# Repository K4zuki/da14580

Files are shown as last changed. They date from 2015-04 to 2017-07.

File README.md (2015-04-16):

# da14580
DA14580/murata module PCBs

<br />This work is licensed under a <a rel="license" href="http://creativecommons.org/licenses/by-sa/4.0/">Creative Commons Attribution-ShareAlike 4.0 International License</a>.

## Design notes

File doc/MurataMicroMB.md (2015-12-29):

# `r0.2` BOM list
| Qty | Value |  AKIZUKI/DIGIKEY/MOUSER  | Parts |
|:---:|:---|:---:|:---|
| | | **DIGIKEY** | |
| 1*  | CORESIGHT10 | 1175-1627-ND | CON3 |
|  1  | 12M/3225 | 1253-1168-1-ND | Q1 |
|  1  | LM27313 | 296-35164-1-ND | IC2 |
| 4*  | TESTPAD\_4020 | 36-5019CT-ND | TP13, TP14, TP15, TP16 |
|  1  | 4.7u/2016 | 445-7844-1-ND | L1 |
|  4  | 0.1u/1005 | 490-3261-1-ND | C1, C7, C10, C11 |
|  4  | 18p/1005 | 490-5858-1-ND | C3, C12, C13, C14 |
|  4  | 4.7u/2012 | 490-9962-1-ND | C4, C5, C8, C9 |
|  1  | IC\_LPC11U35\_QFN33\_5X5 | 568-9586-ND | IC3 |
|  1  | RD/GR | 754-1633-1-ND | LED1 |
| 4*  | TESTPAD\_1608 | A106145CT-ND | TP1, TP2, TP3, TP4 |
|  1  | LDO4\_3.3\_SOT223 | AZ1117EH-3.3TRG1DICT-ND  | IC4 |
| 2*  | CON\_MICROSD\_C2395 | HR1964CT-ND | CON1, CON4 |
|  1  | SINGLE\_74\_00 | NC7SZ00M5XCT-ND | IC5 |
| 4*  | 1k/1005 | P1.00KLCT-ND | R5, R6, R15, R16 |
|  1  | 1.5k/1005 | P1.50KLCT-ND | R11 |
|  9  | 10k/1005 | P10.0KLCT-ND | R2, R7, R8, R9, R12, R17, R18, R19, R20 |
|  2  | 100/1005 | P100LCT-ND | R13, R14 |
|  1  | P13.3KHCT-ND | P13.3KHCT-ND | R4 |
| 2*  | 33/1005 | P33.0LCT-ND | R1, R10 |
|  1  | P60.4KHCT-ND | P60.4KHCT-ND | R3 |
| 1*  | 40V2A | SS24FLCT-ND | D1 |
|  1  | WM17143CT-ND | WM17143CT-ND | CON2 |
| | | **AKIZUKI** | |
|  1  | TSW-102-02-S-S | 1/10 C-08593 | X1 |
|  1  | BSS84 |  I-04269/I-04270(reel) | TR1 |
|  2  | 0.1u/1608 | P-05650 | C2, C15 |
| 2*  | P-8073 | P-08073 | SW1, SW3 |
| 1*  | P-8073 | P-08214 | SW2 |
| | | **NOT\_COMPONENT** | |
|  1  | | ICON\_OSHW | U$1 |
|  8  | | TESTPAD | TP5, TP6, TP7, TP8, TP9, TP10, TP11, TP12 |
|  3  | | TESTPAD\_F | TP101, TP102, TP103 |
|  1  | PCB\_DP\_RECTANGLE-43X70 | PCB\_DP\_RECTANGLE-43X70 | PCB1 |
|  1  | NM/1608 | C\_SMD\_\_1608 | C6 |

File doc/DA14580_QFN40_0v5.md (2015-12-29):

# `v0.5` BOM list
| Qty | Parts | | | |
|:---:|:---|:---|:---|:---|
| | **AKIZUKI** | | | |
|  1  | IC3 | I-05448 | LDO5\_3.3\_SOT23 | LDO5\_3.3\_SOT23 |
| | **DIGIKEY** | | | |
|  1  | L1 | 445-6385-1-ND | 2.2u/1608 | INDUCTOR\_2.2U\_1608 |
|  3  | C4, C5, C10 | 490-3261-1-ND | 0.1u/1005 | C\_SMD\_0.1U\_1005 |
|  4  | C1, C2, C3, C9 | 490-3890-1-ND | 1.0u/1005 | C\_SMD\_1.0U\_1005 |
|  1  | Q1 | 1253-1342-1-ND | 32.768k | CRYSTAL2\_32.768K\_FC-135 |
|  1  | Q2 | 887-1833-1-ND | 16M/2520 | CRYSTAL4\_16M\_2520 |
|  1  | IC2 | NC7SZ00M5XCT-ND | NC7SZ00M5XCT-ND | 74LVC1G00DBV |
|  1  | R1 | P10.0KLCT-ND | 10k/1005 | R\_US\_10K\_1005 |
| | **MOUSER** | | | |
|  1  | U1 | 724-DA14583-01AT2  | DA14583-AT2 | DA14583AT2 |
| | **PLACED BUT UNUSED** | | | |
|  0  | IC1 | 1265-1137-1-ND | AT25XE011\_SOP | IC\_MEMORY\_8P\_AT25XE011\_SOP |
|  0  | X1, X2 | SSW-114-02-S-S | SSW-114-02-S-S | SSW-114-02-S-S |
|  0  | C6 | 490-5921-1-ND | NM | C\_SMD\_10P\_1005 |
|  0  | C7, C8 | NM | C\_SMD\_\_1005 | C0402 |
| | **NOT COMPONENTS** | | | |
|  0  | U$1 | ANT\_IFA | ANT\_IFA | ANT\_IFA\_V2 |
|  0  | CON1 | CON\_TC2030-CTL-NL | CON\_TC2030-CTL-NL | CON\_TC2030-IDC-NL |
|  0  | U$2 | ICON\_OSHW | ICON\_OSHW | ICON\_OSHW |
|  0  | TP1, TP2 | TESTPAD | TESTPAD | TP06RECT |
|  0  | TP91, TP92, TP93 | TESTPAD\_F | TESTPAD\_F | FIDUCIAL |
|  0  | TP3 | TPPAD1-13 | TPPAD1-13 | P1-13 |

Table: http://www.digikey.com/short/t0j4bd

| ID | ref | desc. | count | comment |
|:---|:---|:---|:---|:---|
| 445-6385-1-ND | L1 | FIXED IND 2.2UH 500MA 250 MOHM  | 25 | Cut tape  |
| 1253-1342-1-ND  | Q1 | CRYSTAL 32.7680KHZ 7PF SMD | 25 | Cut tape  |
| 887-1833-1-ND | Q2 | CRYSTAL 16.0000MHZ 12PF SMD | 25 | Cut tape  |
| NC7SZ00M5XCT-ND | IC2 | IC GATE NAND 1CH 2-INP SOT-23-5 | 25 | Cut tape  |
| P10.0KLDKR-ND | R1 | RES SMD 10K OHM 1% 1/10W 0402 | 1000  | Digi-Reel |
| 490-3261-6-ND | C4/ 5/ 10 | CAP CER 0.1UF 16V X7R 0402 | 1000  | Digi-Reel |
| 490-3890-6-ND | C1-3/ 9 | CAP CER 1UF 10V X5R 0402 | 1000  | Digi-Reel |

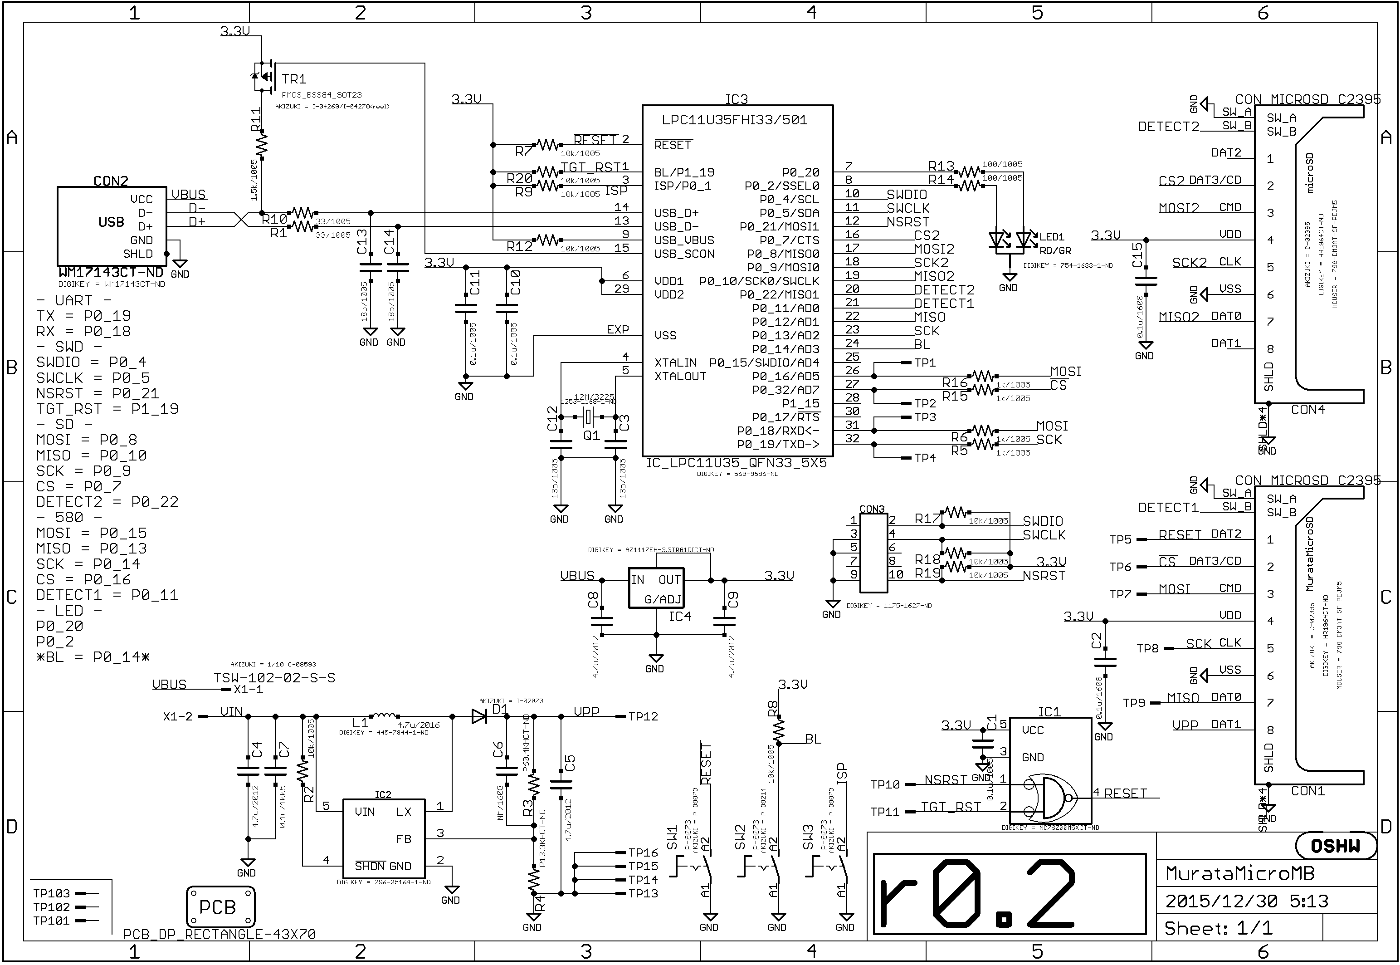
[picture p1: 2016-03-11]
images/MurataMicroMBr02.sch.png

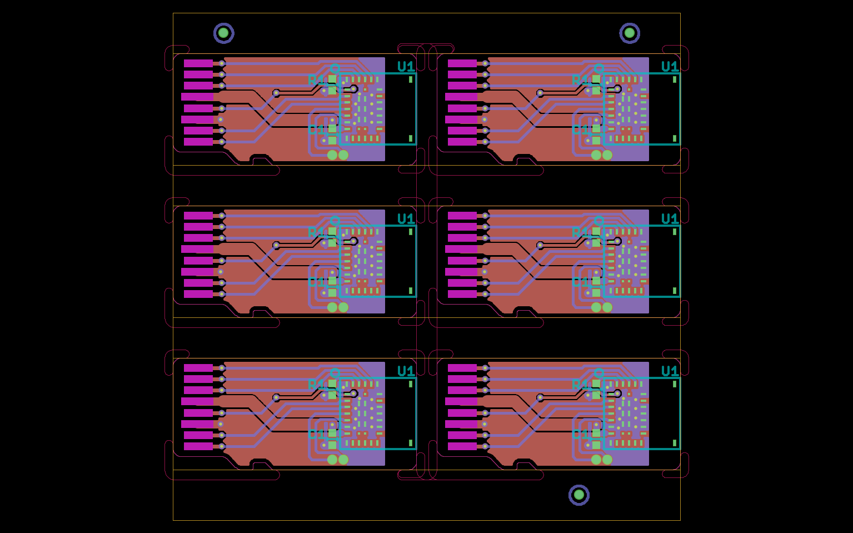
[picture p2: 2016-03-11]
images/MurataMicroSD_P.png

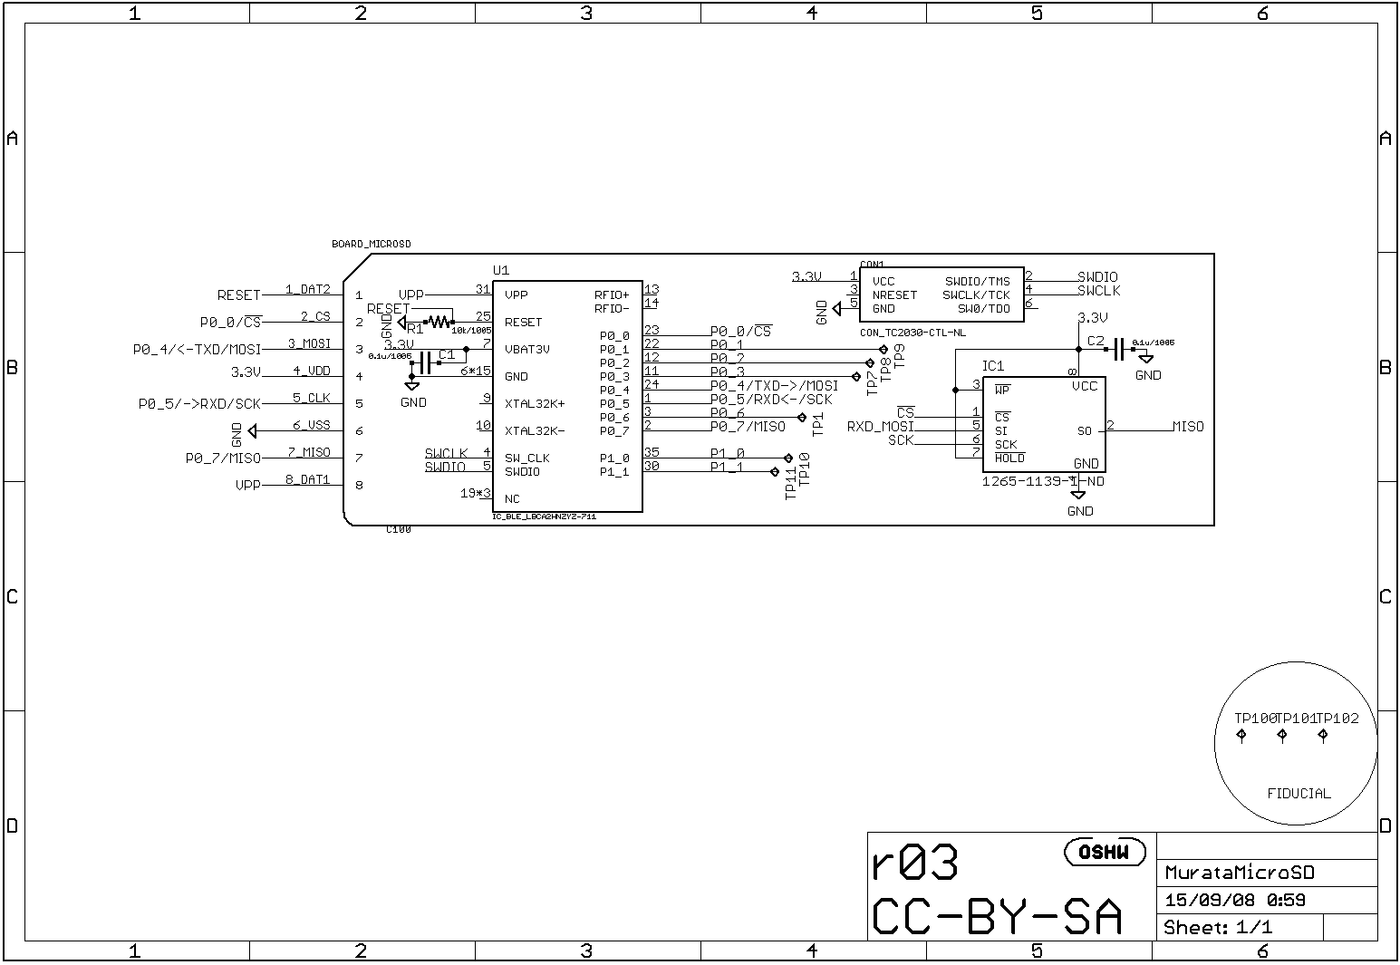
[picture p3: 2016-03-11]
images/MurataMicroSD.sch.png

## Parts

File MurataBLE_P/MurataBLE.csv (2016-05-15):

Part | Value | Device | Package | Description | AKIZUKI | DIGIKEY | MOUSER | NOT_COMPONENT | SEEED
C1 | 1u/1608 | C_SMD_1.0U_1608 | CR_1608 | SMD CAPACITOR |  |  |  |  | 302010139
C2 | 0.1u/1005 | C_SMD_0.1U_1005 | C0402 | SMD CAPACITOR |  | 490-3261-1-ND |  |  | 302010024
C3 | 1u/1608 | C_SMD_1.0U_1608 | CR_1608 | SMD CAPACITOR |  |  |  |  | 302010139
C4 | 0.1u/1005 | C_SMD_0.1U_1005 | C0402 | SMD CAPACITOR |  | 490-3261-1-ND |  |  | 302010024
C5 | 0.1u/1005 | C_SMD_0.1U_1005 | C0402 | SMD CAPACITOR |  | 490-3261-1-ND |  |  | 302010024
C6 | 0.1u/1005 | C_SMD_0.1U_1005 | C0402 | SMD CAPACITOR |  | 490-3261-1-ND |  |  | 302010024
C7 | 18p/1005 | C_SMD_18P_1005 | C0402 | SMD CAPACITOR |  | 490-5858-1-ND |  |  | 302010016
C8 | 18p/1005 | C_SMD_18P_1005 | C0402 | SMD CAPACITOR |  | 490-5858-1-ND |  |  | 302010016
C9 | 18p/1005 | C_SMD_18P_1005 | C0402 | SMD CAPACITOR |  | 490-5858-1-ND |  |  | 302010016
C10 | 18p/1005 | C_SMD_18P_1005 | C0402 | SMD CAPACITOR |  | 490-5858-1-ND |  |  | 302010016
C13 | 0.1u/1005 | C_SMD_0.1U_1005 | C0402 | SMD CAPACITOR |  | 490-3261-1-ND |  |  | 302010024
CON1 | 47589-0001 | CON_USB_UB | CON_USB_47589-0001MOLEX | USB B CONNECTOR |  | WM17143CT-ND
IC1 | TLV1117-33IDRJR | LDO4_3.3_DRJ | DFN80P410X410_8N | LDO with 4 pins |  | 296-32364-1-ND
IC2 | LPC11U35_QFN33 | IC_LPC11U35_QFN33_5X5 | HVQFN33 |  |  | 568-9586-ND |  |  | 310010053
IC3 | NC7SZ00 | IC_TTL_SINGLE_74_00_SOT23 | SOT95P280X145-5N | SINGLE 2-INPUT POSITIVE-OR GATE |  | NC7SZ00M5XCT-ND
LED1 | LED_3SEG | LED_3SEG | LED_3SEG_SMD | Vf@5mA: |  |  | 604-APF3236SEEZGQBDC
LED2 | LED_3SEG | LED_3SEG | LED_3SEG_SMD | Vf@5mA: |  |  | 604-APF3236SEEZGQBDC
Q1 | 32.768K/2012 | CRYSTAL2_32.768K_2012 | CR_2125 |  |  | 1253-1342-1-ND
Q2 | 12M/3225 | CRYSTAL4_12M_3225 | CLOCK_3225 | Crystal 4 pins |  | 1253-1168-1-ND
R1 | 10k/1005 | R_US_10K_1005 | C0402 | SMD resistor |  | P10.0KLCT-ND |  |  | 301010047
R2 | 33/1005 | R_US_33R_1005 | C0402 | SMD resistor |  | P33.0LCT-ND |  |  | 301010609
R3 | 33/1005 | R_US_33R_1005 | C0402 | SMD resistor |  | P33.0LCT-ND |  |  | 301010609
R4 | 1k/1005 | R_US_1.0K_1005 | C0402 | SMD resistor |  | P1.00KLCT-ND |  |  | 301010006
R5 | 1k/1005 | R_US_1.0K_1005 | C0402 | SMD resistor |  | P1.00KLCT-ND |  |  | 301010006
R6 | 10k/1005 | R_US_10K_1005 | C0402 | SMD resistor |  | P10.0KLCT-ND |  |  | 301010047
R7 | 10k/1005 | R_US_10K_1005 | C0402 | SMD resistor |  | P10.0KLCT-ND |  |  | 301010047
R8 | 10k/1005 | R_US_10K_1005 | C0402 | SMD resistor |  | P10.0KLCT-ND |  |  | 301010047
R9 | 10k/1005 | R_US_10K_1005 | C0402 | SMD resistor |  | P10.0KLCT-ND |  |  | 301010047
R10 | 1.5k/1005 | R_US_1.5K_1005 | C0402 | SMD resistor |  | P1.50KLCT-ND |  |  | 301010001
R11 | 1k/1005 | R_US_1.0K_1005 | C0402 | SMD resistor |  | P1.00KLCT-ND |  |  | 301010006
R14 | 10k/1005 | R_US_10K_1005 | C0402 | SMD resistor |  | P10.0KLCT-ND |  |  | 301010047
R15 | 10k/1005 | R_US_10K_1005 | C0402 | SMD resistor |  | P10.0KLCT-ND |  |  | 301010047
R16 | 1k/1005 | R_US_1.0K_1005 | C0402 | SMD resistor |  | P1.00KLCT-ND |  |  | 301010006
R17 | 1k/1005 | R_US_1.0K_1005 | C0402 | SMD resistor |  | P1.00KLCT-ND |  |  | 301010006
R18 | 1k/1005 | R_US_1.0K_1005 | C0402 | SMD resistor |  | P1.00KLCT-ND |  |  | 301010006
SW1 | FSM2JMTR | TACTSW2_FSM2JMTR | SW_TACTSW_FSM2JMTR | 2P tact switch |  | 450-2146-1-ND
SW2 | FSM2JMTR | TACTSW2_FSM2JMTR | SW_TACTSW_FSM2JMTR | 2P tact switch |  | 450-2146-1-ND
SW3 | FSM2JMTR | TACTSW2_FSM2JMTR | SW_TACTSW_FSM2JMTR | 2P tact switch |  | 450-2146-1-ND
TR1 | BSS84 | PMOS_BSS84_SOT23 | SOT95P300X140-3N |  | I-04269/I-04270(reel) | BSS84CT-ND
U1 | LBCA2HNZYZ | LBCA2HNZYZ-711 | IC_MURATA_LBCA2HNZYZ-711 |  |  | 490-10561-1-ND | 81-LBCA2HNZYZ-711

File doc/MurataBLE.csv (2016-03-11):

Qty | Value | Device | Package | Parts | Description | AKIZUKI | DIGIKEY | MOUSER | NOT_COMPONENT | SEEED
1 |  | CON_USB_UB | CON_USB_47589-0001MOLEX | CON1 | USB B CONNECTOR |  | WM17143CT-ND
1 |  | CRYSTAL2_32.768K_2012 | CR_2125 | Q1 |  |  | 1253-1342-1-ND
1 |  | CRYSTAL4_12M_3225 | CLOCK_3225 | Q2 | Crystal 4 pins |  | 1253-1168-1-ND
1 |  | GIT-REVISION | GIT-REVISION | GIT1 |  |  |  |  | YES
1 |  | ICON_OSHW | ICON_OSHW | ICON2 | Silk icon of OSHW |  |  |  | YES
1 |  | IC_LPC11U35_QFN33_5X5 | HVQFN33 | IC2 |  |  | 568-9586-ND |  |  | 310010053
1 |  | IC_MEMORY_8P_AT25DN512C_SOP | IC_08_1.27_150MIL | IC4 |  |  |  | 988-A25DN512CSSHFGPT (cuttape)
1 |  | IC_MEMORY_8P_AT25XE011_SOP | IC_08_1.27_150MIL | IC5 |  |  | 1265-1137-1-ND
1 |  | IC_TTL_SINGLE_74_00_SOT23 | SOT95P280X145-5N | IC3 | SINGLE 2-INPUT POSITIVE-OR GATE |  | NC7SZ00M5XCT-ND
1 |  | LBCA2HNZYZ-711 | IC_MURATA_LBCA2HNZYZ-711 | U1 |  |  | 490-10561-1-ND | 81-LBCA2HNZYZ-711
4 |  | PCB_CORNER_NH | PCB_CORNER_NH | P1, P2, P3, P4 |  |  |  |  | YES
3 |  | R_US_1.0K_1005 | C0402 | R4, R5, R11 | SMD resistor |  | P1.00KLCT-ND |  |  | 301010006
2 |  | R_US__1005SHORT | R0402SHORT | R12, R13 | SMD resistor |  |  |  | YES
3 |  | TACTSW2_FSM2JMTR | SW_TACTSW_FSM2JMTR | SW1, SW2, SW3 | 2P tact switch |  | 450-2146-1-ND
7 | 0.1u/1005 | C_SMD_0.1U_1005 | C0402 | C2, C4, C5, C6, C11, C12, C13 | SMD CAPACITOR |  | 490-3261-1-ND |  |  | 302010024
1 | 1.5k/1005 | R_US_1.5K_1005 | C0402 | R10 | SMD resistor |  | P1.50KLCT-ND |  |  | 301010001
5 | 10k/1005 | R_US_10K_1005 | C0402 | R1, R6, R7, R8, R9 | SMD resistor |  | P10.0KLCT-ND |  |  | 301010047
4 | 18p/1005 | C_SMD_18P_1005 | C0402 | C7, C8, C9, C10 | SMD CAPACITOR |  | 490-5858-1-ND |  |  | 302010016
2 | 1u/1608 | C_SMD_1.0U_1608 | CR_1608 | C1, C3 | SMD CAPACITOR |  |  |  |  | 302010139
2 | 33/1005 | R_US_33R_1005 | C0402 | R2, R3 | SMD resistor |  | P33.0LCT-ND |  |  | 301010609
1 | I-5448 | LDO5_3.3_SOT23 | SOT95P280X145-5N | IC1 |  | I-05448
1 | LED_3SEG | LED_3SEG | LED_3SEG_SMD | LED1 | Vf@5mA: |  |  | 604-APF3236SEEZGQBDC
1 | PMOS_BSS84_SOT23 | PMOS_BSS84_SOT23 | SOT95P300X140-3N | TR1 |  | I-04269/I-04270(reel) | BSS84CT-ND
3 | TESTPAD_F | TESTPAD_F | FIDUCIAL | TP100, TP101, TP102 | test points |  |  |  | YES
2 | TSW-114-02-S-S | TSW-114-02-S-S | TSW-114-07-F-S | X1, X2 | THROUGH-HOLE .025inch SQ POST HEADER | C-04397 |  |  | YES
1 | r0.4 | ICON_REVISION_1.2 | ICON_REVISION1.2 | ICON1 |  |  |  |  | YES

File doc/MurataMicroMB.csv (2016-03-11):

Qty | Value | Parts | DIGIKEY | SEEED
1 | CON_MIL_10_ARM | CON3 | 1175-1627-ND
1 | LM27313 | IC2 | 296-35164-1-ND
1 | NC7SZ00 | IC1 | NC7SZ00M5XCT-ND
1 | LDO4_3.3_DRJ | IC4 | 296-32364-1-ND
3 | TACTSW2_FSM2JMTR | SW1, SW2, SW3 | 450-2146-1-ND
4 | TESTPAD_4020 | TP13, TP14, TP15, TP16 | 36-5019CT-ND
4 | 0.1u/1005 | C1, C7, C10, C11 | 490-3261-1-ND | 302010024
1 | 1.5k/1005 | R11 | P1.50KLCT-ND | 301010001
9 | 10k/1005 | R2, R7, R8, R9, R12, R17, R18, R19, R20 | P10.0KLCT-ND | 301010047
1 | 12M/3225 | Q1 | 1253-1168-1-ND
4 | 18p/1005 | C3, C12, C13, C14 | 490-5858-1-ND | 302010016
4 | 1k/1005 | R5, R6, R15, R16 | P1.00KLCT-ND | 301010006
2 | 33/1005 | R1, R10 | P33.0LCT-ND | 301010609
4 | 4.7u/2012 | C4, C5, C8, C9 | 490-9962-1-ND
1 | 4.7u/2016 | L1 | 445-7844-1-ND
1 | 40V2A | D1 | SS24FLCT-ND
2 | CON_MICROSD_C2395 | CON1, CON4 | HR1964CT-ND
1 | LPC11U35_5X5 | IC3 | 568-9586-ND | 310010053
1 | 13.3K/1608 | R4 | P13.3KHCT-ND
1 | BSS84 | TR1 | BSS84CT-ND
4 | TESTPAD_1608 | TP1, TP2, TP3, TP4 | A106145CT-ND
1 | TSW-102-02-S-S | X1 | S1011EC-02-ND | 320020016
1 | WM17143CT-ND | CON2 | WM17143CT-ND

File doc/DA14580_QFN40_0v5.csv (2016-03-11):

Qty | Parts | AKIZUKI | DIGIKEY | MOUSER
1 | IC3 | I-05448 | LDO5_3.3_SOT23 | LDO5_3.3_SOT23
1 | IC1 | 1265-1137-1-ND | AT25XE011_SOP | IC_MEMORY_8P_AT25XE011_SOP
1 | L1 | 445-6385-1-ND | 2.2u/1608 | INDUCTOR_2.2U_1608
3 | C4, C5, C10 | 490-3261-1-ND | 0.1u/1005 | C_SMD_0.1U_1005
4 | C1, C2, C3, C9 | 490-3890-1-ND | 1.0u/1005 | C_SMD_1.0U_1005
1 | Q1 | 728-1076-1-ND | 32.768k | CRYSTAL2_32.768K_FC-135
1 | Q2 | 887-1833-1-ND | 16M/2520 | CRYSTAL4_16M_2520
1 | IC2 | NC7SZ00M5XCT-ND | NC7SZ00M5XCT-ND | 74LVC1G00DBV
1 | R1 | P10.0KLCT-ND | 10k/1005 | R_US_10K_1005
1 | U1 | 724-DA14583-01AT2 | DA14583-AT2 | DA14583AT2
0 | X1, X2 | SSW-114-02-S-S | SSW-114-02-S-S | SSW-114-02-S-S
0 | U$1 | ANT_IFA | ANT_IFA | ANT_IFA_V2
0 | CON1 | CON_TC2030-CTL-NL | CON_TC2030-CTL-NL | CON_TC2030-IDC-NL
0 | U$2 | ICON_OSHW | ICON_OSHW | ICON_OSHW
0 | C6 | 490-5921-1-ND | NM | C_SMD_10P_1005
0 | C7, C8 | NM | C_SMD__1005 | C0402
0 | TP1, TP2 | TESTPAD | TESTPAD | TP06RECT
0 | TP91, TP92, TP93 | TESTPAD_F | TESTPAD_F | FIDUCIAL
0 | TP3 | TPPAD1-13 | TPPAD1-13 | P1-13

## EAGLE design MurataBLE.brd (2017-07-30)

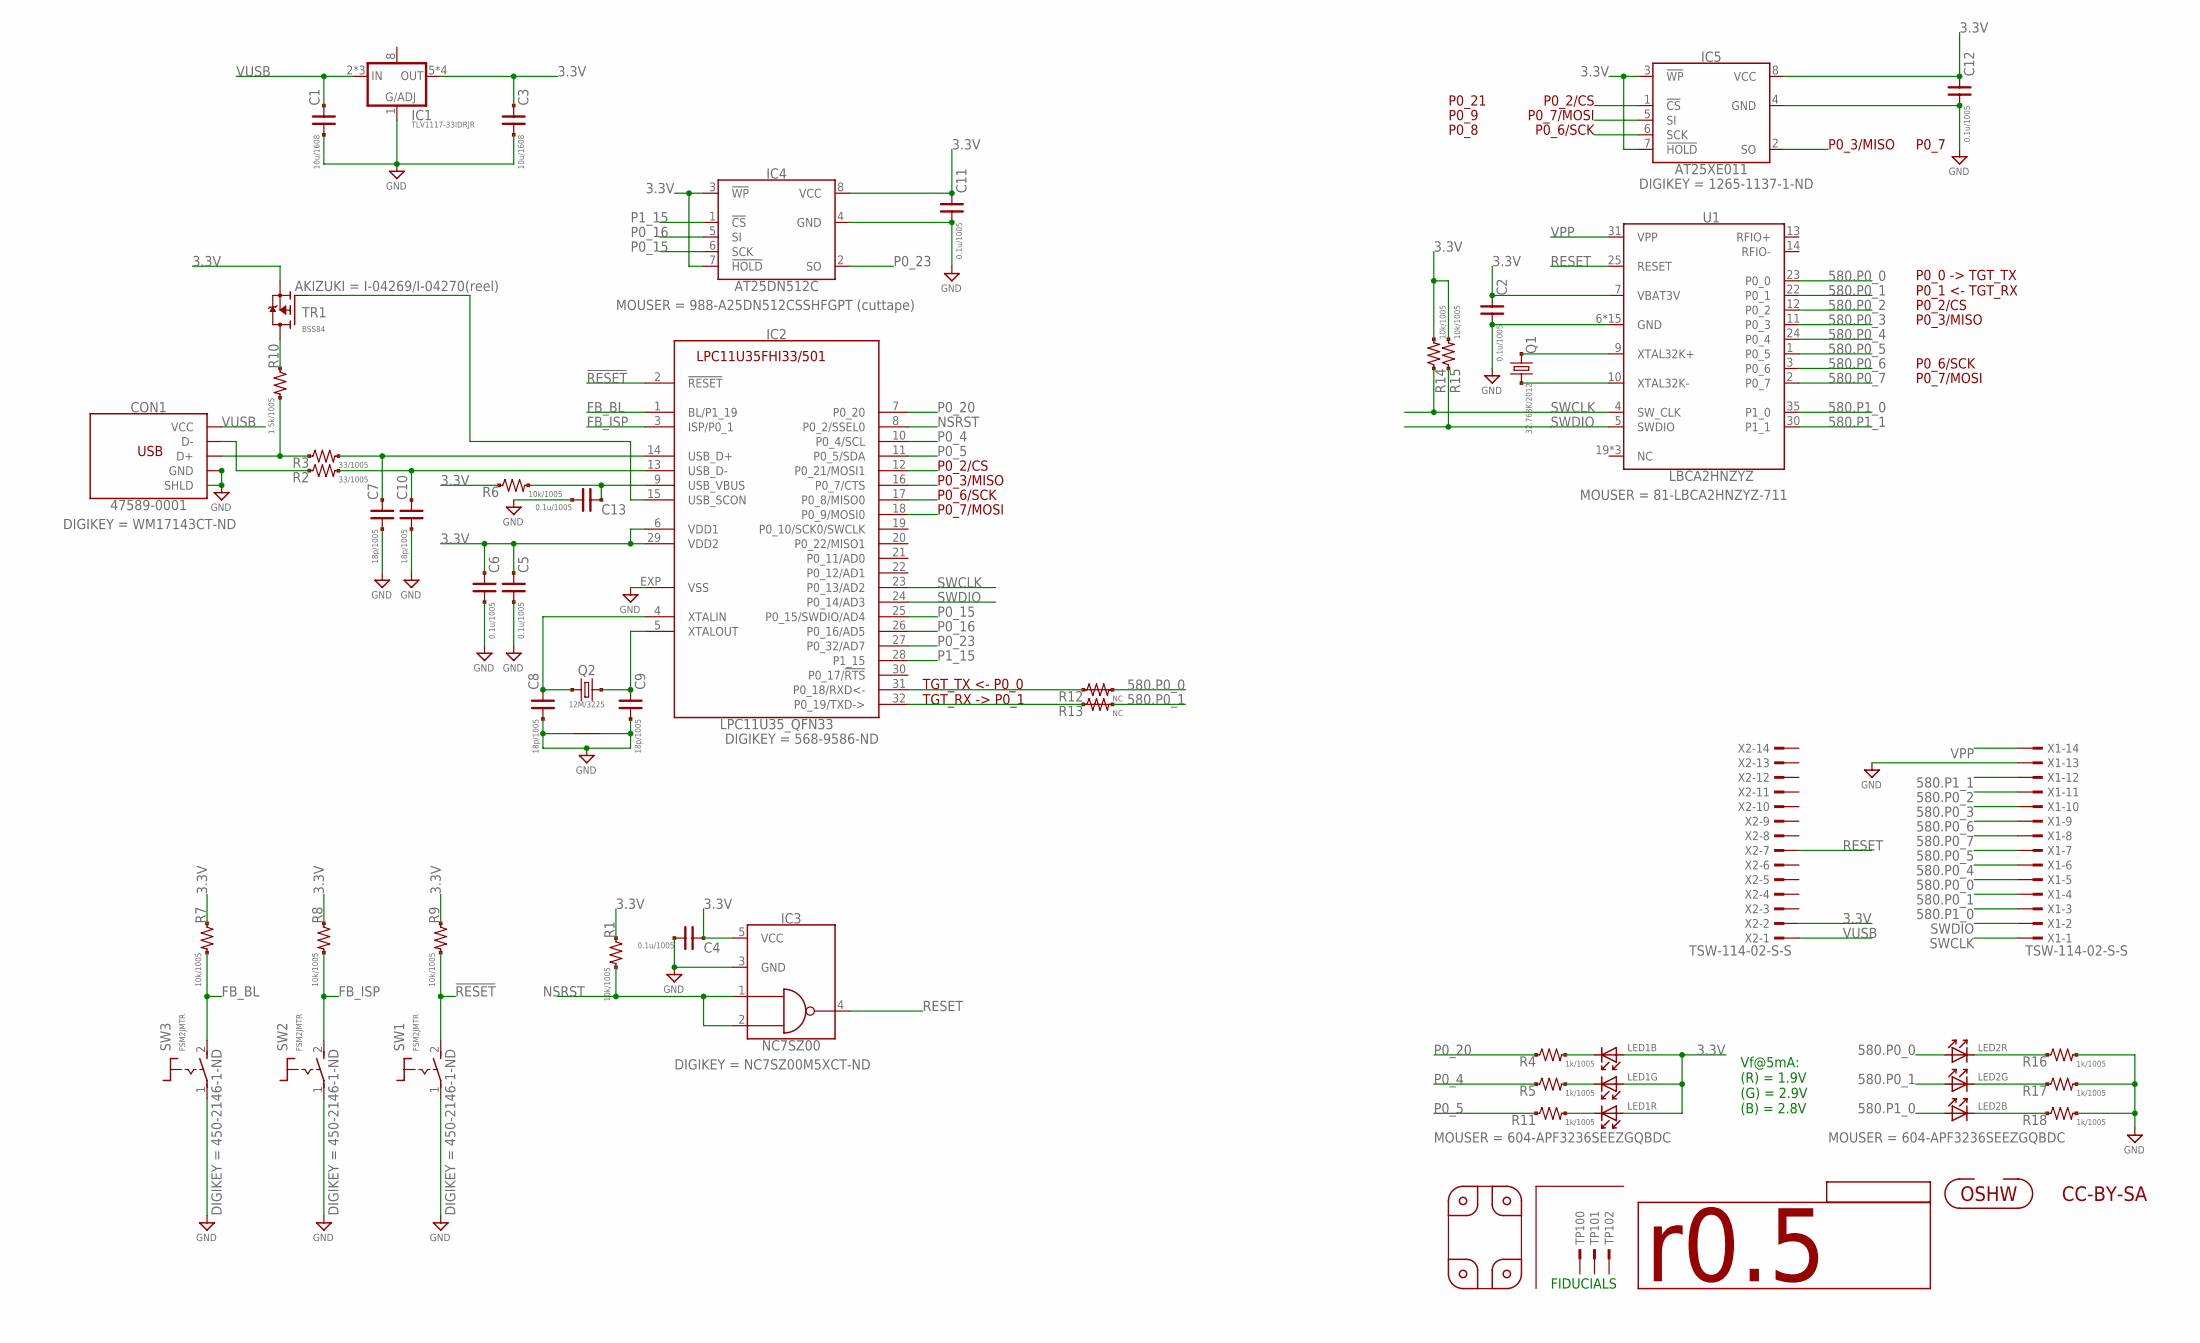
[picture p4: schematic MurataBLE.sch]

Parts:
C1, C3: 10u/1608; CR_1608
C2, C4, C5, C6, C11, C12, C13: 0.1u/1005; C0402
C7, C8, C9, C10: 18p/1005; C0402
CON1: 47589-0001; CON_USB_47589-0001MOLEX
GIT1: GIT-REVISION
IC1: TLV1117-33IDRJR; DFN80P410X410_8N
IC2: LPC11U35_QFN33; HVQFN33
IC3: NC7SZ00; SOT95P280X145-5N
IC4: AT25DN512C; IC_08_1.27_150MIL
IC5: AT25XE011; IC_08_1.27_150MIL
ICON1: r0.5; ICON_REVISION1.2
ICON2: NC; ICON_OSHW
LED1, LED2: LED_3SEG; LED_3SEG_SMD
P1, P2, P3, P4: NC; PCB_CORNER_NH
Q1: 32.768K/2012; CR_2125
Q2: 12M/3225; CLOCK_3225
R1, R6, R7, R8, R9, R14, R15: 10k/1005; C0402
R2, R3: 33/1005; C0402
R4, R5, R11, R16, R17, R18: 1k/1005; C0402
R10: 1.5k/1005; C0402
R12, R13: NC; R0402SHORT
SW1, SW2, SW3: FSM2JMTR; SW_TACTSW_FSM2JMTR
TP100, TP101, TP102: NC; FIDUCIAL
TR1: BSS84; SOT95P300X140-3N
U1: LBCA2HNZYZ; IC_MURATA_LBCA2HNZYZ-711
X1, X2: TSW-114-02-S-S; TSW-114-07-F-S

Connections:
3.3V: C2.1, C3.1, C4.1, C5.1, C6.1, C11.1, C12.1, IC1.5 (OUT), IC1.6 (OUT), IC1.7 (OUT), IC1.EP (OUT), IC2.6 (VDD1), IC2.29 (VDD2), IC3.5 (VCC), IC4.3 (!WP), IC4.7 (!HOLD), IC4.8 (VCC), IC5.3 (!WP), IC5.7 (!HOLD), IC5.8 (VCC), LED1.4 (A), LED1.5 (A), LED1.6 (A), R1.1, R6.1, R7.1, R8.1, R9.1, R14.2, R15.2, TR1.2 (S), U1.7 (VBAT3V), X2.2
580.P0_0: LED2.4 (A), R12.3 (2), U1.23 (P0_0), X1.5
580.P0_1: LED2.5 (A), R13.3 (2), U1.22 (P0_1), X1.4
580.P0_2: IC2.12 (P0_21/MOSI1), IC5.1 (!CS), U1.12 (P0_2), X1.11
580.P0_3: IC2.16 (P0_7/CTS), IC5.2 (SO), U1.11 (P0_3), X1.10
580.P0_4: U1.24 (P0_4), X1.6
580.P0_5: U1.1 (P0_5), X1.7
580.P0_6: IC2.17 (P0_8/MISO0), IC5.6 (SCK), U1.3 (P0_6), X1.9
580.P0_7: IC2.18 (P0_9/MOSI0), IC5.5 (SI), U1.2 (P0_7), X1.8
580.P1_0: LED2.6 (A), U1.35 (P1_0), X1.3
580.P1_1: U1.30 (P1_1), X1.12
!RESET!: IC2.2 (!RESET!), R9.2, SW1.2 (S)
FB_BL: IC2.1 (BL/P1_19), R7.2, SW3.2 (S)
FB_ISP: IC2.3 (ISP/P0_1), R8.2, SW2.2 (S)
GND: C1.2, C2.2, C3.2, C4.2, C5.2, C6.2, C7.2, C8.2, C9.2, C10.2, C11.2, C12.2, C13.2, CON1.5 (GND), CON1.SHD (SHLD), CON1.SHD$1 (SHLD), CON1.SHD$2 (SHLD), CON1.SHD$3 (SHLD), CON1.SHD$4 (SHLD), CON1.SHD$5 (SHLD), CON1.SHD$6 (SHLD), CON1.SHD$7 (SHLD), IC1.1 (ADJ), IC2.EXP (VSS), IC3.3 (GND), IC4.4 (GND), IC5.4 (GND), Q2.2, Q2.4, R16.2, R17.2, R18.2, SW1.1, SW2.1, SW3.1, U1.6 (GND), U1.8 (GND), U1.15 (GND), U1.16 (GND), U1.17 (GND), U1.18 (GND), U1.20 (GND), U1.21 (GND), U1.26 (GND), U1.27 (GND), U1.28 (GND), U1.29 (GND), U1.32 (GND), U1.33 (GND), U1.34 (GND), X1.13
unnamed: Q1.1, U1.9 (XTAL32K+)
unnamed: Q1.2, U1.10 (XTAL32K-)
unnamed: C13.1, IC2.9 (USB_VBUS), R6.2
unnamed: R10.1, TR1.3 (D)
unnamed: IC2.15 (USB_SCON), TR1.1 (G)
unnamed: LED1.1 (K), R11.2
unnamed: LED1.2 (K), R5.2
unnamed: LED1.3 (K), R4.2
unnamed: LED2.3 (K), R18.1
unnamed: LED2.2 (K), R17.1
unnamed: LED2.1 (K), R16.1
unnamed: C8.1, IC2.4 (XTALIN), Q2.1
unnamed: C9.1, IC2.5 (XTALOUT), Q2.3 (2)
unnamed: C7.1, IC2.14 (USB_D+), R3.2
unnamed: CON1.3 (D+), R3.1, R10.2
unnamed: CON1.2 (D-), R2.1
unnamed: C10.1, IC2.13 (USB_D-), R2.2
NSRST: IC2.8 (P0_2/SSEL0), IC3.1 (1A), IC3.2 (1B), R1.2
P0_4: IC2.10 (P0_4/SCL), R5.1
P0_5: IC2.11 (P0_5/SDA), R11.1
P0_15: IC2.25 (P0_15/SWDIO/AD4), IC4.6 (SCK)
P0_16: IC2.26 (P0_16/AD5), IC4.5 (SI)
P0_20: IC2.7 (P0_20), R4.1
P0_23: IC2.27 (P0_32/AD7), IC4.2 (SO)
P1_15: IC2.28 (P1_15), IC4.1 (!CS)
RESET: IC3.4 (1Y), U1.25 (RESET), X2.7
SWCLK: IC2.23 (P0_13/AD2), R14.1, U1.4 (SW_CLK), X1.1
SWDIO: IC2.24 (P0_14/AD3), R15.1, U1.5 (SWDIO), X1.2
TGT_RX: IC2.32 (P0_19/TXD->), R13.1, R13.2 (1)
TGT_TX: IC2.31 (P0_18/RXD<-), R12.1, R12.2 (1)
VPP: U1.31 (VPP), X1.14
VUSB: C1.1, CON1.1 (VCC), IC1.2 (IN), IC1.3 (IN), IC1.4 (IN), X2.1

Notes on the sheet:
Vf@5mA: (R) = 1.9V (G) = 2.9V (B) = 2.8V
TGT_TX <- P0_0 TGT_RX -> P0_1
P0_0 -> TGT_TX P0_1 <- TGT_RX
CC-BY-SA
FIDUCIALS
P0_2/CS
P0_7/MOSI
P0_3/MISO
P0_6/SCK
P0_21
P0_9
P0_8
P0_7

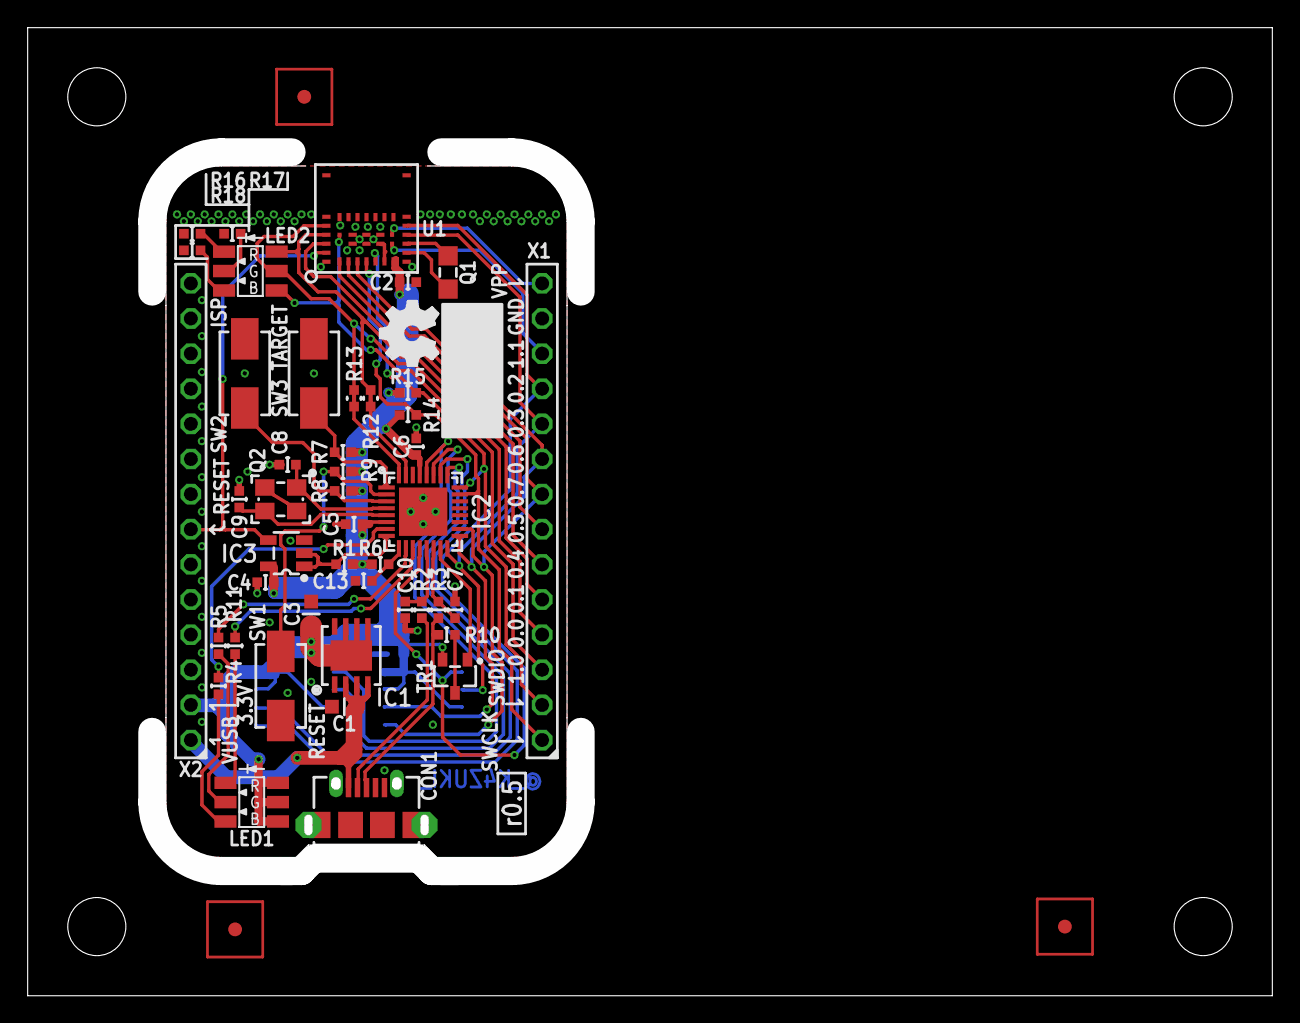
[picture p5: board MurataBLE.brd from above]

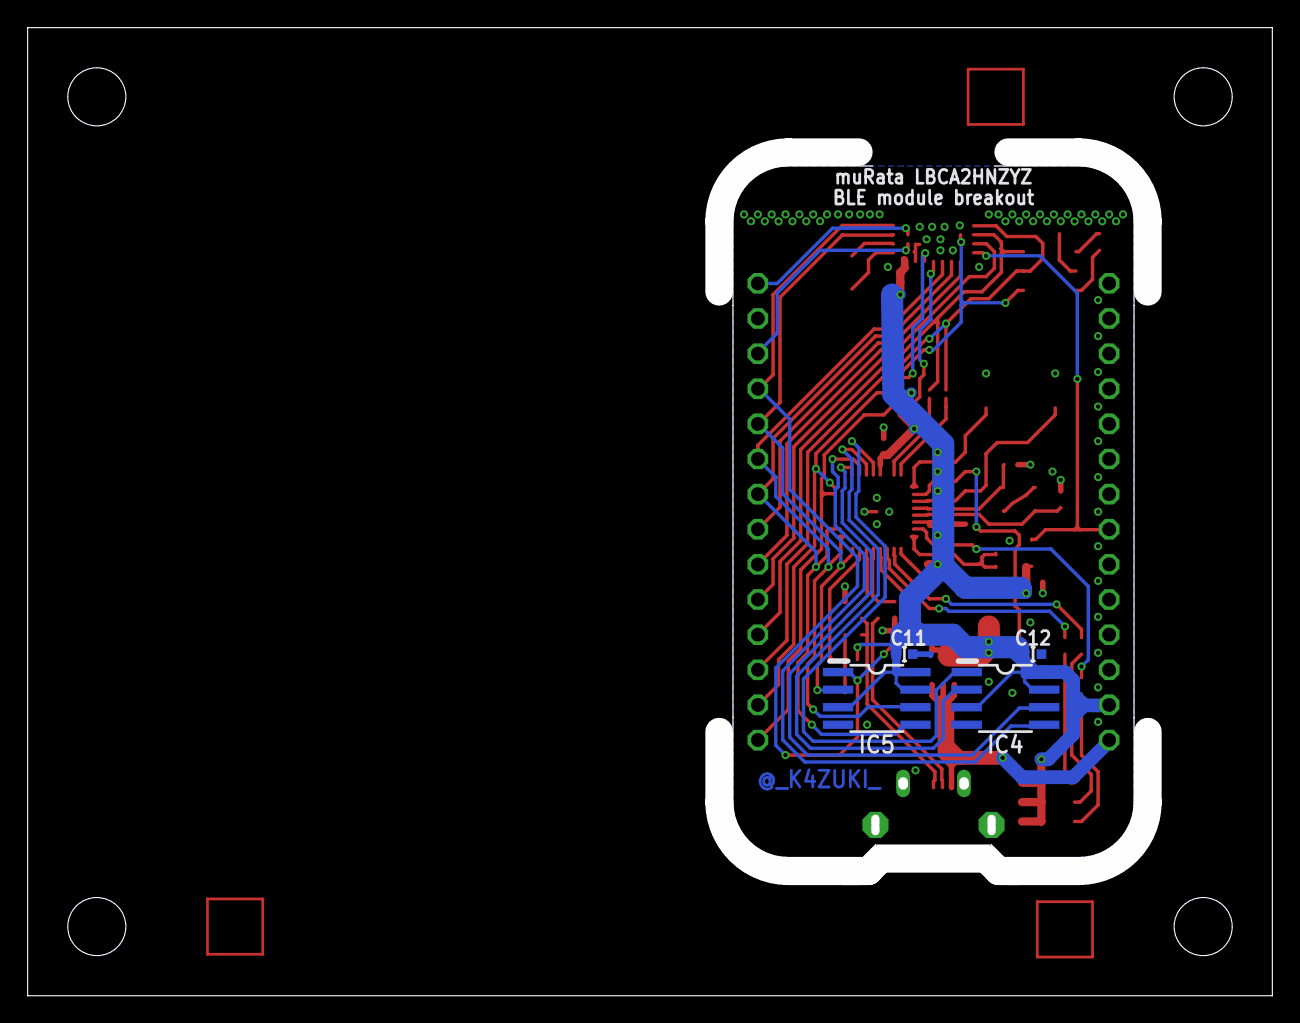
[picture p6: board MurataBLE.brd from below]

Board: 2 copper layers, 90.0 x 70.0 mm, 58 parts (4 on the bottom side), 47 nets.

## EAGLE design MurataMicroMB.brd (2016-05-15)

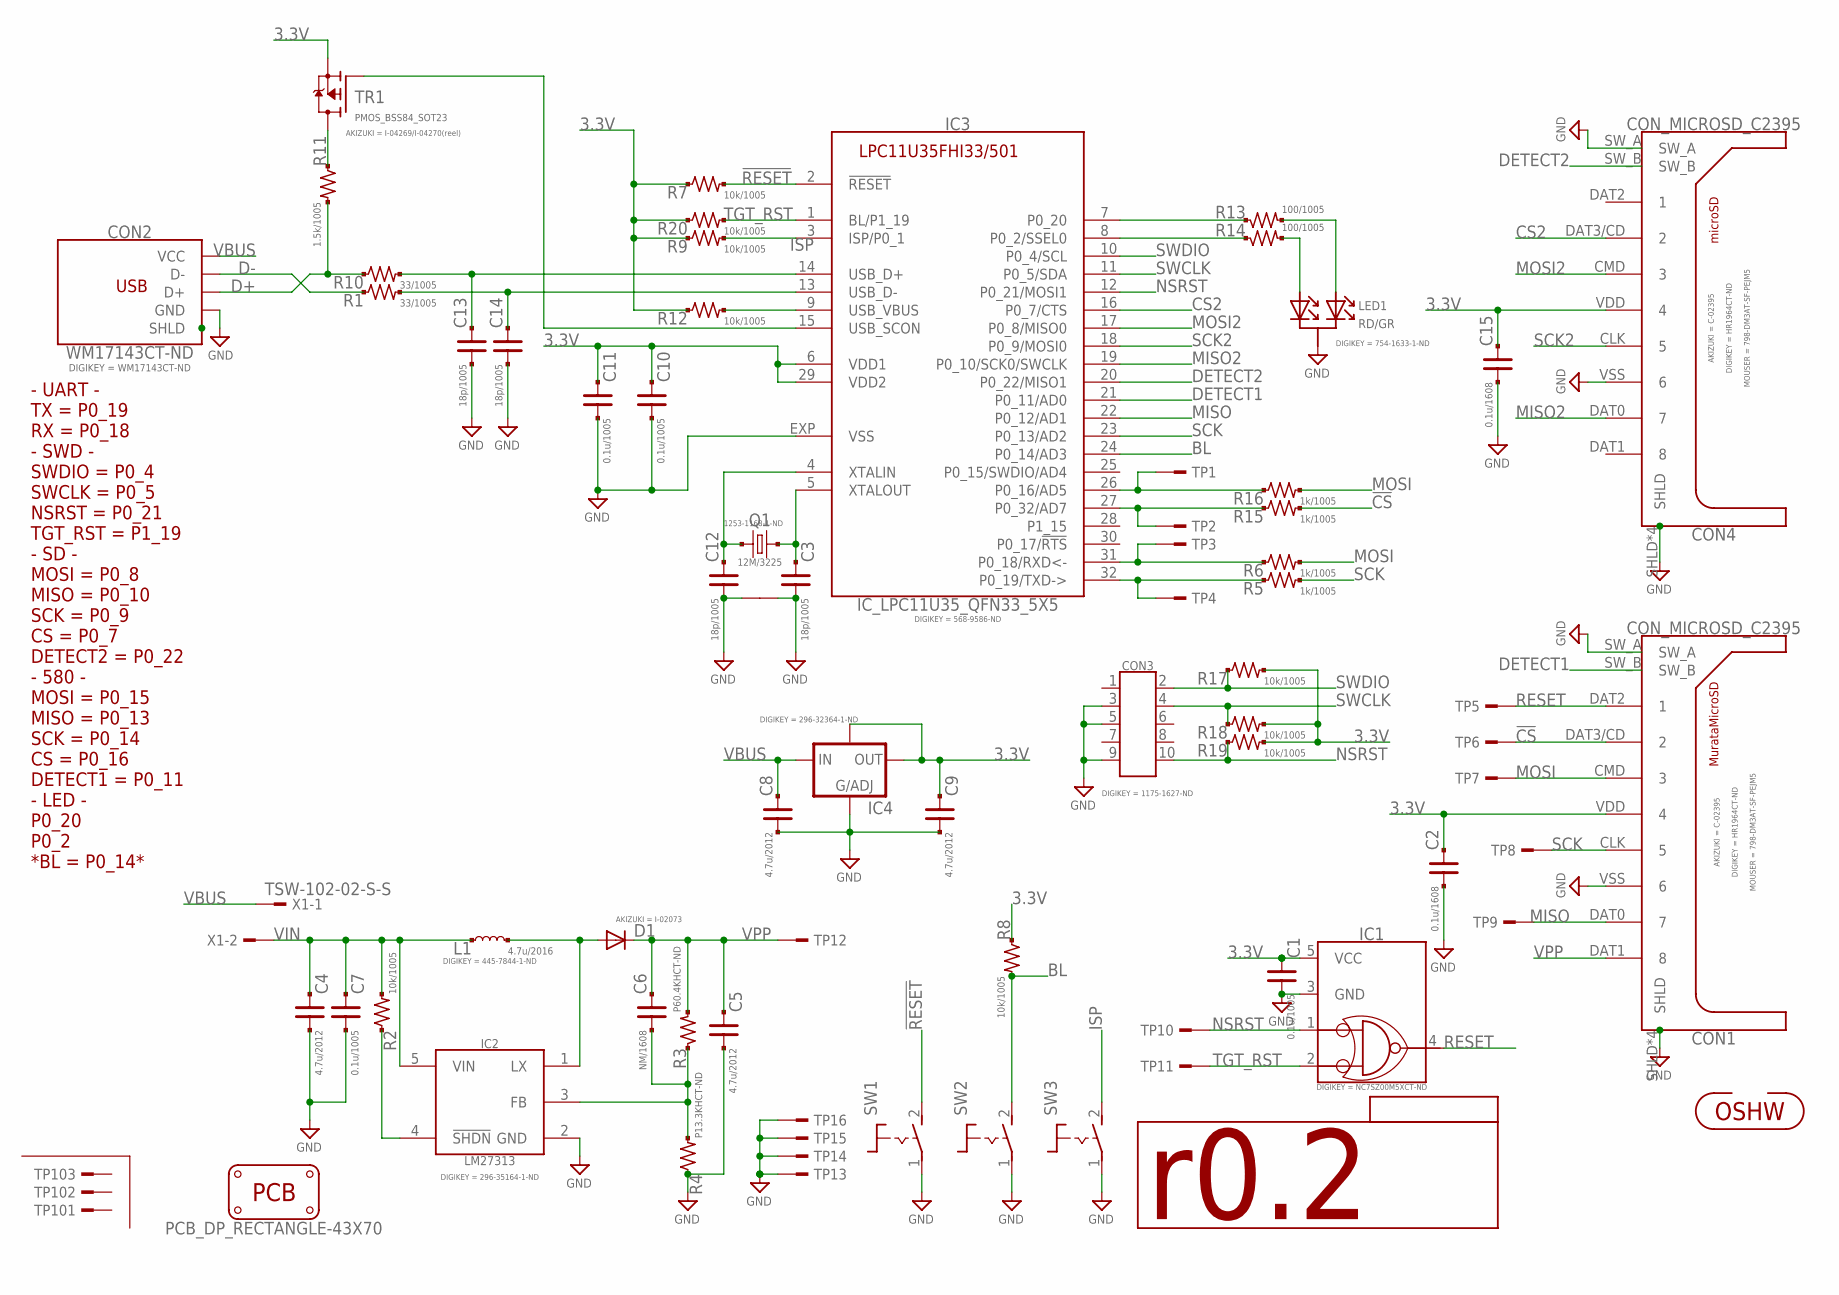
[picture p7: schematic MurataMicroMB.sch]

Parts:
C1, C7, C10, C11: 0.1u/1005; C0402
C2, C15: 0.1u/1608; CR_1608
C3, C12, C13, C14: 18p/1005; C0402
C4, C5, C8, C9: 4.7u/2012; CR_2125
C6: NM/1608; CR_1608
CON1, CON4: CON_MICROSD_C2395
CON2: WM17143CT-ND; CON_USB_47589-0001MOLEX
CON3: CON_MIL_10_ARM; CON_CORESIGHT10_1175-1627-ND
D1: 40V2A; DIODE_2125
GIT1: GIT-REVISION
IC1: IC_TTL_SINGLE_74_00_SOT23; SOT95P280X145-5N
IC2: LM27313; SOT95P280X145-5N
IC3: IC_LPC11U35_QFN33_5X5; HVQFN33
IC4: LDO4_3.3_DRJ; DFN80P410X410_8N
ICON1: r0.2; ICON_REVISION2.0
L1: 4.7u/2016; L_2016
LED1: RD/GR; SOT105P300X130-3N
PCB1: PCB_DP_RECTANGLE-43X70; DP7043_V1
Q1: 12M/3225; CLOCK_3225
R1, R10: 33/1005; C0402
R2, R7, R8, R9, R12, R17, R18, R19, R20: 10k/1005; C0402
R3: P60.4KHCT-ND; R_1608_PADPAD
R4: P13.3KHCT-ND; R_1608_PADPAD
R5, R6, R15, R16: 1k/1005; C0402
R11: 1.5k/1005; C0402
R13, R14: 100/1005; C0402
SW1, SW2, SW3: TACTSW2_FSM2JMTR; SW_TACTSW_FSM2JMTR
TP1, TP2, TP3, TP4: TESTPAD_1608; TP_1608
TP5, TP6, TP7, TP8, TP9, TP10, TP11, TP12: TESTPAD; TP06RECT
TP13, TP14, TP15, TP16: TESTPAD_4020; TP_4020
TP101, TP102, TP103: TESTPAD_F; FIDUCIAL
TR1: PMOS_BSS84_SOT23; SOT95P300X140-3N
U$1: ICON_OSHW
X1: TSW-102-02-S-S

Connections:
3.3V: C1.1, C2.1, C9.1, C10.1, C11.1, C15.1, CON1.VDD (4), CON4.VDD (4), IC1.5 (VCC), IC3.6 (VDD1), IC3.29 (VDD2), IC4.5 (OUT), IC4.6 (OUT), IC4.7 (OUT), IC4.8 (OUT/EN/NC), IC4.EP (OUT), R7.1, R8.1, R9.1, R12.1, R17.2, R18.2, R19.2, R20.1, TR1.2 (S)
!CS!: CON1.DAT3/CD (2), R15.2, TP6.TP
!RESET!: IC3.2 (!RESET!), R7.2, SW1.2 (S)
BL: IC3.24 (P0_14/AD3), R8.2, SW2.2 (S)
CS2: CON4.DAT3/CD (2), IC3.16 (P0_7/CTS)
D+: CON2.3 (D+), R10.1, R11.2
D-: CON2.2 (D-), R1.1
DETECT1: CON1.SW_B, IC3.21 (P0_11/AD0)
DETECT2: CON4.SW_B, IC3.20 (P0_22/MISO1)
GND: C1.2, C2.2, C3.2, C4.2, C5.2, C7.2, C8.2, C9.2, C10.2, C11.2, C12.2, C13.2, C14.2, C15.2, CON1.SHLD, CON1.SHLD@2 (SHLD), CON1.SHLD@3 (SHLD), CON1.SHLD@4 (SHLD), CON1.SW_A, CON1.VSS (6), CON2.5 (GND), CON3.3, CON3.5, CON3.9, CON4.SHLD, CON4.SHLD@2 (SHLD), CON4.SHLD@3 (SHLD), CON4.SHLD@4 (SHLD), CON4.SW_A, CON4.VSS (6), IC1.3 (GND), IC2.2 (GND), IC3.EXP (VSS), IC4.1 (ADJ), LED1.3 (K1), Q1.2, Q1.4, R4.1, SW1.1, SW2.1, SW3.1, TP13.TP, TP14.TP, TP15.TP, TP16.TP
ISP: IC3.3 (ISP/P0_1), R9.2, SW3.2 (S)
MISO: CON1.DAT0 (7), IC3.22 (P0_12/AD1), TP9.TP
MISO2: CON4.DAT0 (7), IC3.19 (P0_10/SCK0/SWCLK)
MOSI: CON1.CMD (3), R6.2, R16.2, TP7.TP
MOSI2: CON4.CMD (3), IC3.17 (P0_8/MISO0)
unnamed: IC3.8 (P0_2/SSEL0), R14.1
unnamed: R11.1, TR1.3 (D)
unnamed: CON2.SHD (SHLD), CON2.SHD$1 (SHLD), CON2.SHD$2 (SHLD), CON2.SHD$3 (SHLD), CON2.SHD$4 (SHLD), CON2.SHD$5 (SHLD), CON2.SHD$6 (SHLD), CON2.SHD$7 (SHLD)
unnamed: C12.1, IC3.4 (XTALIN), Q1.1
unnamed: IC3.31 (P0_18/RXD<-), R6.1, TP3.TP
unnamed: D1.A, IC2.1 (LX), L1.2
unnamed: IC2.4 (!SHDN!), R2.1
unnamed: IC3.32 (P0_19/TXD->), R5.1, TP4.TP
unnamed: C6.2, IC2.3 (FB), R3.1, R4.2
unnamed: C3.1, IC3.5 (XTALOUT), Q1.3 (2)
unnamed: IC3.15 (USB_SCON), TR1.1 (G)
unnamed: IC3.9 (USB_VBUS), R12.2
unnamed: IC3.7 (P0_20), R13.1
unnamed: LED1.2 (A2), R13.2
unnamed: LED1.1 (A1), R14.2
unnamed: IC3.26 (P0_16/AD5), R16.1, TP1.TP
unnamed: IC3.27 (P0_32/AD7), R15.1, TP2.TP
unnamed: C13.1, IC3.14 (USB_D+), R10.2
unnamed: C14.1, IC3.13 (USB_D-), R1.2
NSRST: CON3.10, IC1.1 (1A), IC3.12 (P0_21/MOSI1), R19.1, TP10.TP
RESET: CON1.DAT2 (1), IC1.4 (1Y), TP5.TP
SCK: CON1.CLK (5), IC3.23 (P0_13/AD2), R5.2, TP8.TP
SCK2: CON4.CLK (5), IC3.18 (P0_9/MOSI0)
SWCLK: CON3.4, IC3.11 (P0_5/SDA), R18.1
SWDIO: CON3.2, IC3.10 (P0_4/SCL), R17.1
TGT_RST: IC1.2 (1B), IC3.1 (BL/P1_19), R20.2, TP11.TP
VBUS: C8.1, CON2.1 (VCC), IC4.2 (IN), IC4.3 (IN), IC4.4 (IN), X1.1
VIN: C4.1, C7.1, IC2.5 (VIN), L1.1, R2.2, X1.2
VPP: C5.1, C6.1, CON1.DAT1 (8), D1.K (C), R3.2, TP12.TP

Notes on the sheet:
MurataMicroSD
microSD
- UART - TX = P0_19 RX = P0_18 - SWD - SWDIO = P0_4 SWCLK = P0_5 NSRST = P0_21 TGT_RST = P1_19 - SD - MOSI = P0_8 MISO = P0_10 SCK = P0_9 CS = P0_7 DETECT2 = P0_22 - 580 - MOSI = P0_15 MISO = P0_13 SCK = P0_14 CS = P0_16 DETECT1 = P0_11 - LED - P0_20 P0_2 *BL = P0_14*

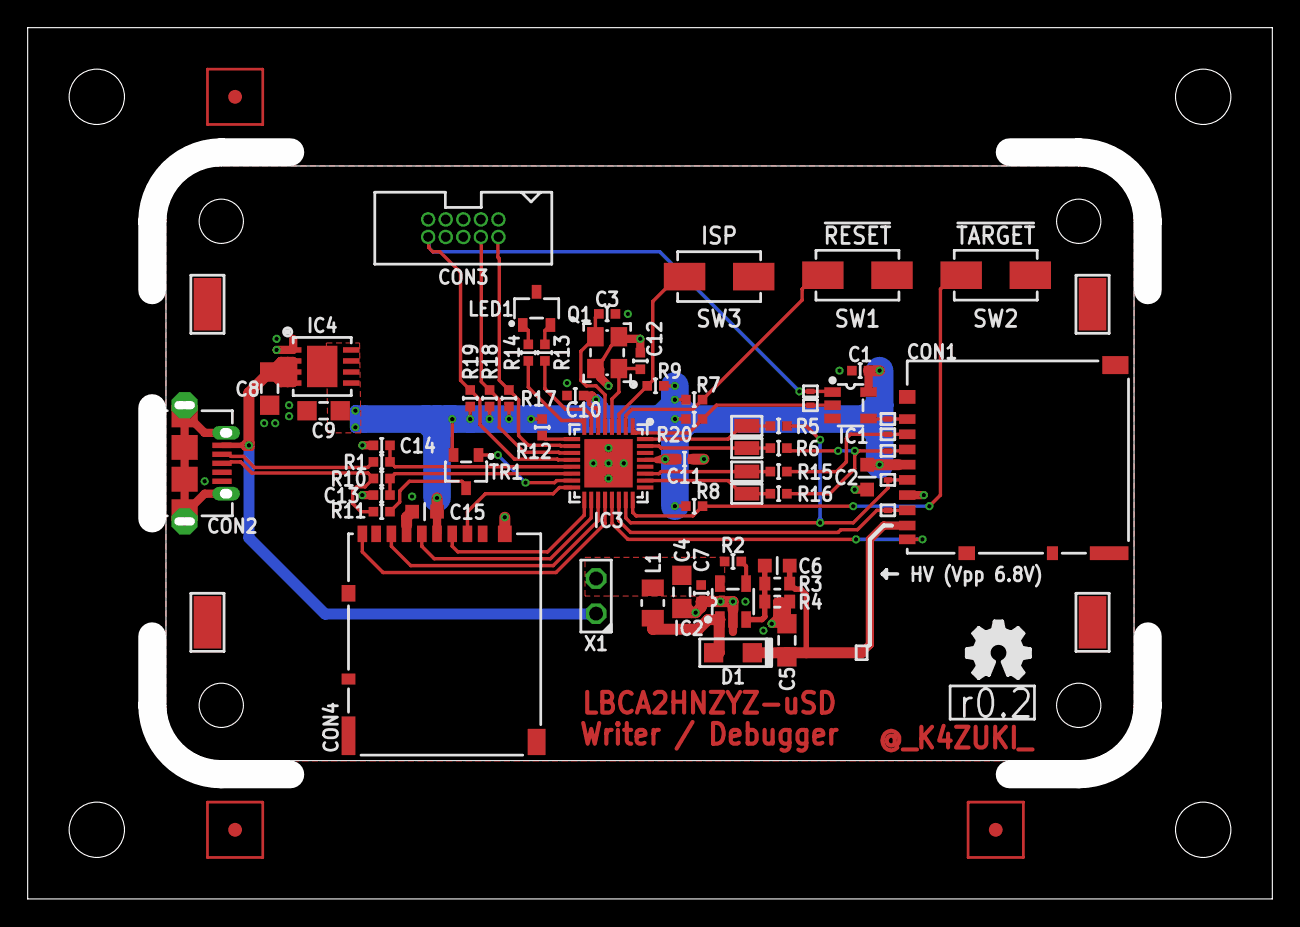
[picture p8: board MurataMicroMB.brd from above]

Board: 2 copper layers, 90.0 x 63.0 mm, 75 parts (0 on the bottom side), 44 nets.

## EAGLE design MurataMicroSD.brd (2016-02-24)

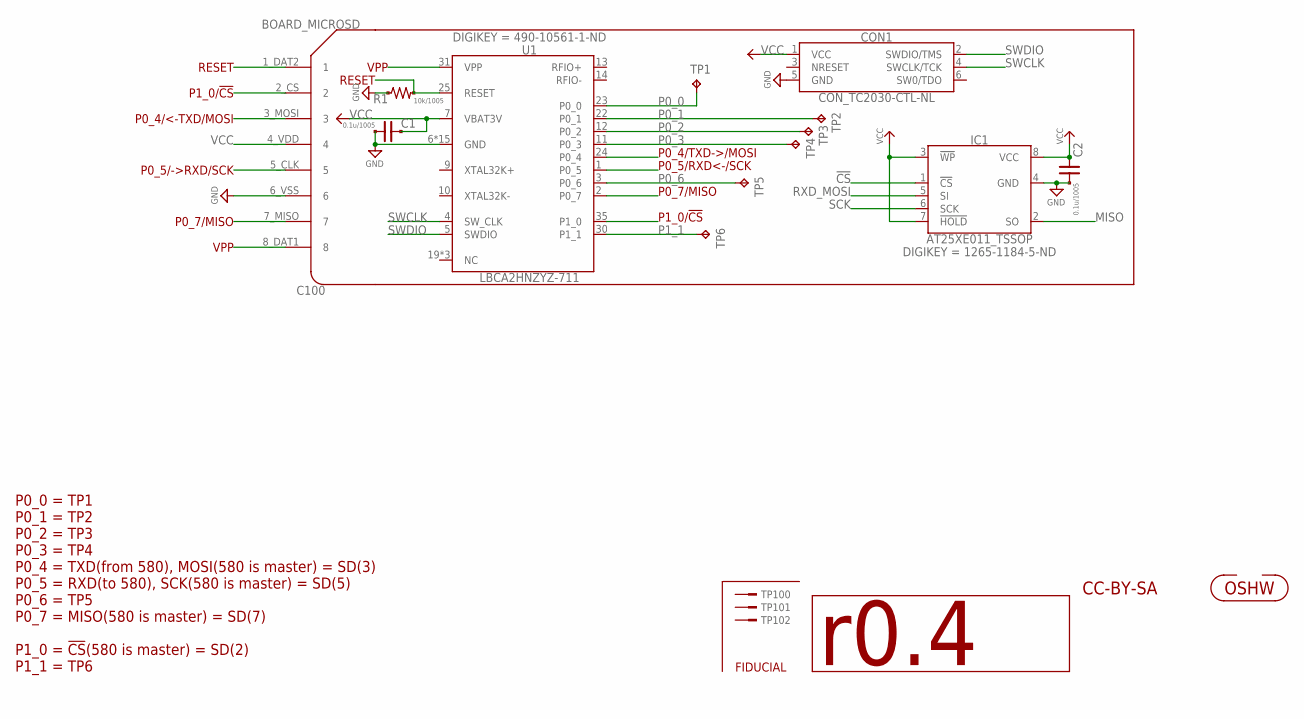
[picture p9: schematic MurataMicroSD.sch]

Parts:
C1, C2: 0.1u/1005; C0402
C100: BOARD_MICROSD
CON1: CON_TC2030-CTL-NL; CON_TC2030-IDC-NL
IC1: AT25XE011_TSSOP; IC_08_0.65_160MIL
ICON1: r0.4; ICON_REVISION1.2
R1: 10k/1005; C0402
TP1, TP2, TP3, TP4, TP5, TP6: TPTP08R; TP08R
TP100, TP101, TP102: TESTPAD_F; FIDUCIAL
U1: LBCA2HNZYZ-711; IC_MURATA_LBCA2HNZYZ-711
U$1: ICON_OSHW

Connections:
!CS!: C100.2_CS (2), IC1.1 (!CS), U1.35 (P1_0)
GND: C1.2, C2.2, C100.6_VSS (6), CON1.5 (GND), IC1.4 (GND), R1.1, U1.6 (GND), U1.8 (GND), U1.15 (GND), U1.16 (GND), U1.17 (GND), U1.18 (GND), U1.20 (GND), U1.21 (GND), U1.26 (GND), U1.27 (GND), U1.28 (GND), U1.29 (GND), U1.32 (GND), U1.33 (GND), U1.34 (GND)
MISO: C100.7_MISO (7), IC1.2 (SO), U1.2 (P0_7)
unnamed: C100.1_DAT2 (1), R1.2, U1.25 (RESET)
P0_0: TP1.TP, U1.23 (P0_0)
P0_1: TP2.TP, U1.22 (P0_1)
P0_2: TP3.TP, U1.12 (P0_2)
P0_3: TP4.TP, U1.11 (P0_3)
P0_6: TP5.TP, U1.3 (P0_6)
P1_1: TP6.TP, U1.30 (P1_1)
RXD_MOSI: C100.3_MOSI (3), IC1.5 (SI), U1.24 (P0_4)
SCK: C100.5_CLK (5), IC1.6 (SCK), U1.1 (P0_5)
SWCLK: CON1.4 (SWCLK/TCK), U1.4 (SW_CLK)
SWDIO: CON1.2 (SWDIO/TMS), U1.5 (SWDIO)
VCC: C1.1, C2.1, C100.4_VDD (4), CON1.1 (VCC), IC1.3 (!WP), IC1.7 (!HOLD), IC1.8 (VCC), U1.7 (VBAT3V)
VPP: C100.8_DAT1 (8), U1.31 (VPP)

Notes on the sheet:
FIDUCIAL
P1_0/!CS!
P0_4/TXD->/MOSI
P0_5/RXD<-/SCK
RESET
P0_5/->RXD/SCK
P0_4/<-TXD/MOSI
P0_7/MISO
CC-BY-SA
VPP
P0_0 = TP1 P0_1 = TP2 P0_2 = TP3 P0_3 = TP4 P0_4 = TXD(from 580), MOSI(580 is master) = SD(3) P0_5 = RXD(to 580), SCK(580 is master) = SD(5) P0_6 = TP5 P0_7 = MISO(580 is master) = SD(7) P1_0 = !CS!(580 is master) = SD(2) P1_1 = TP6

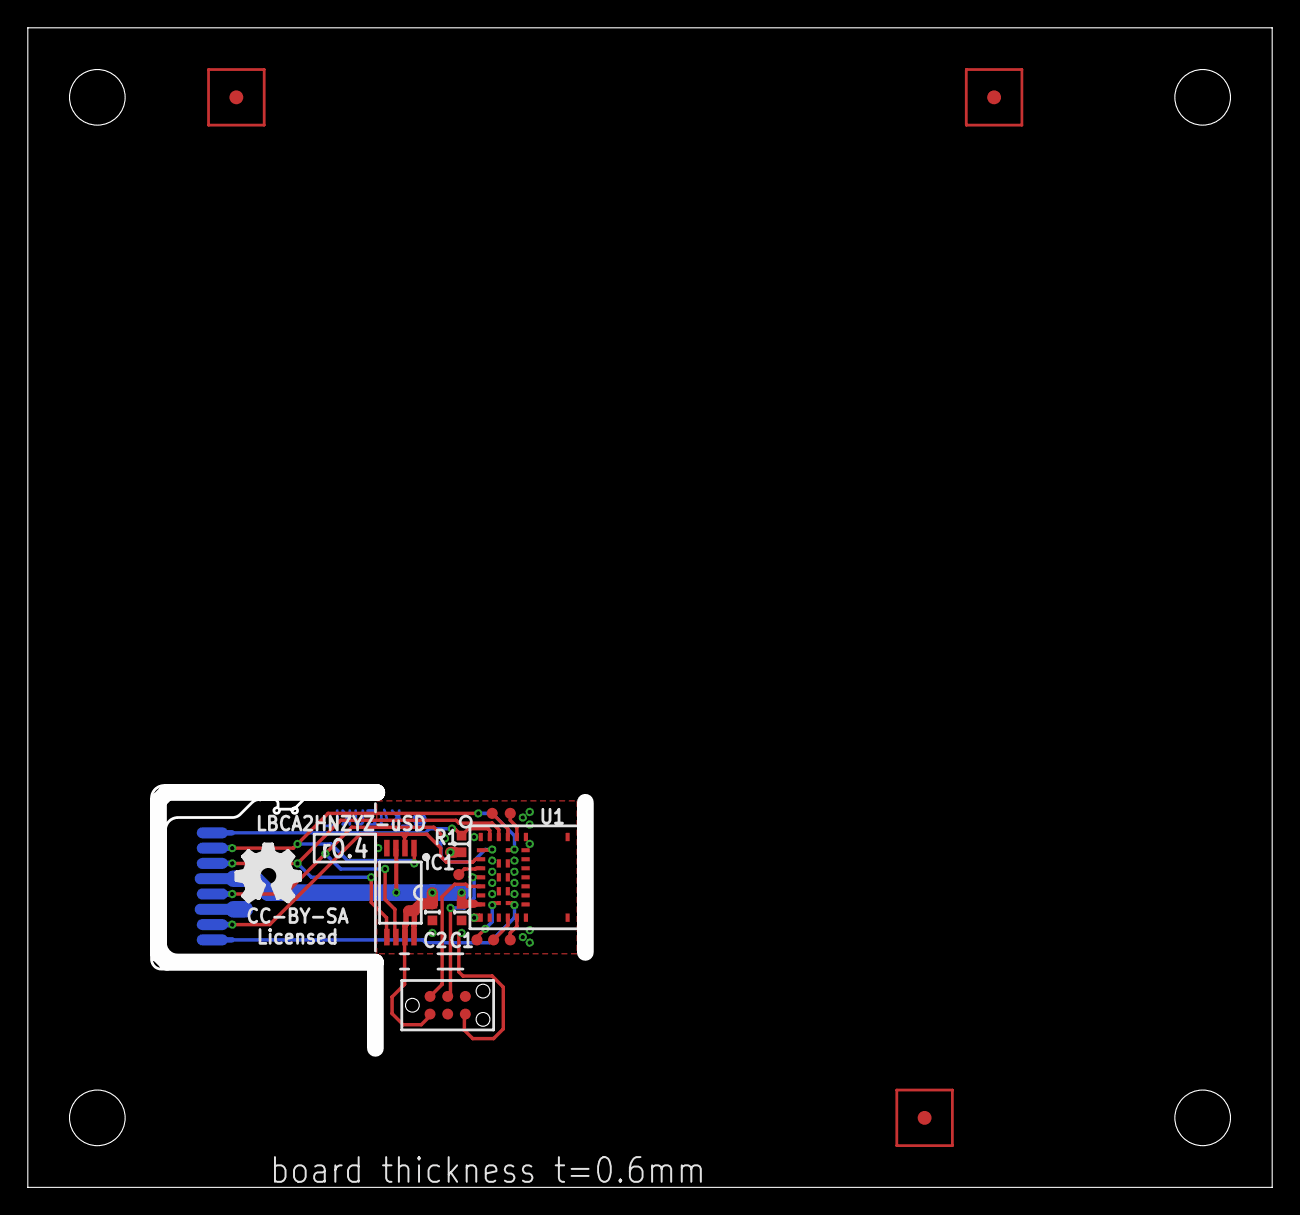
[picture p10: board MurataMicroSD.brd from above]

Board: 2 copper layers, 89.5 x 83.4 mm, 18 parts (1 on the bottom side), 16 nets.

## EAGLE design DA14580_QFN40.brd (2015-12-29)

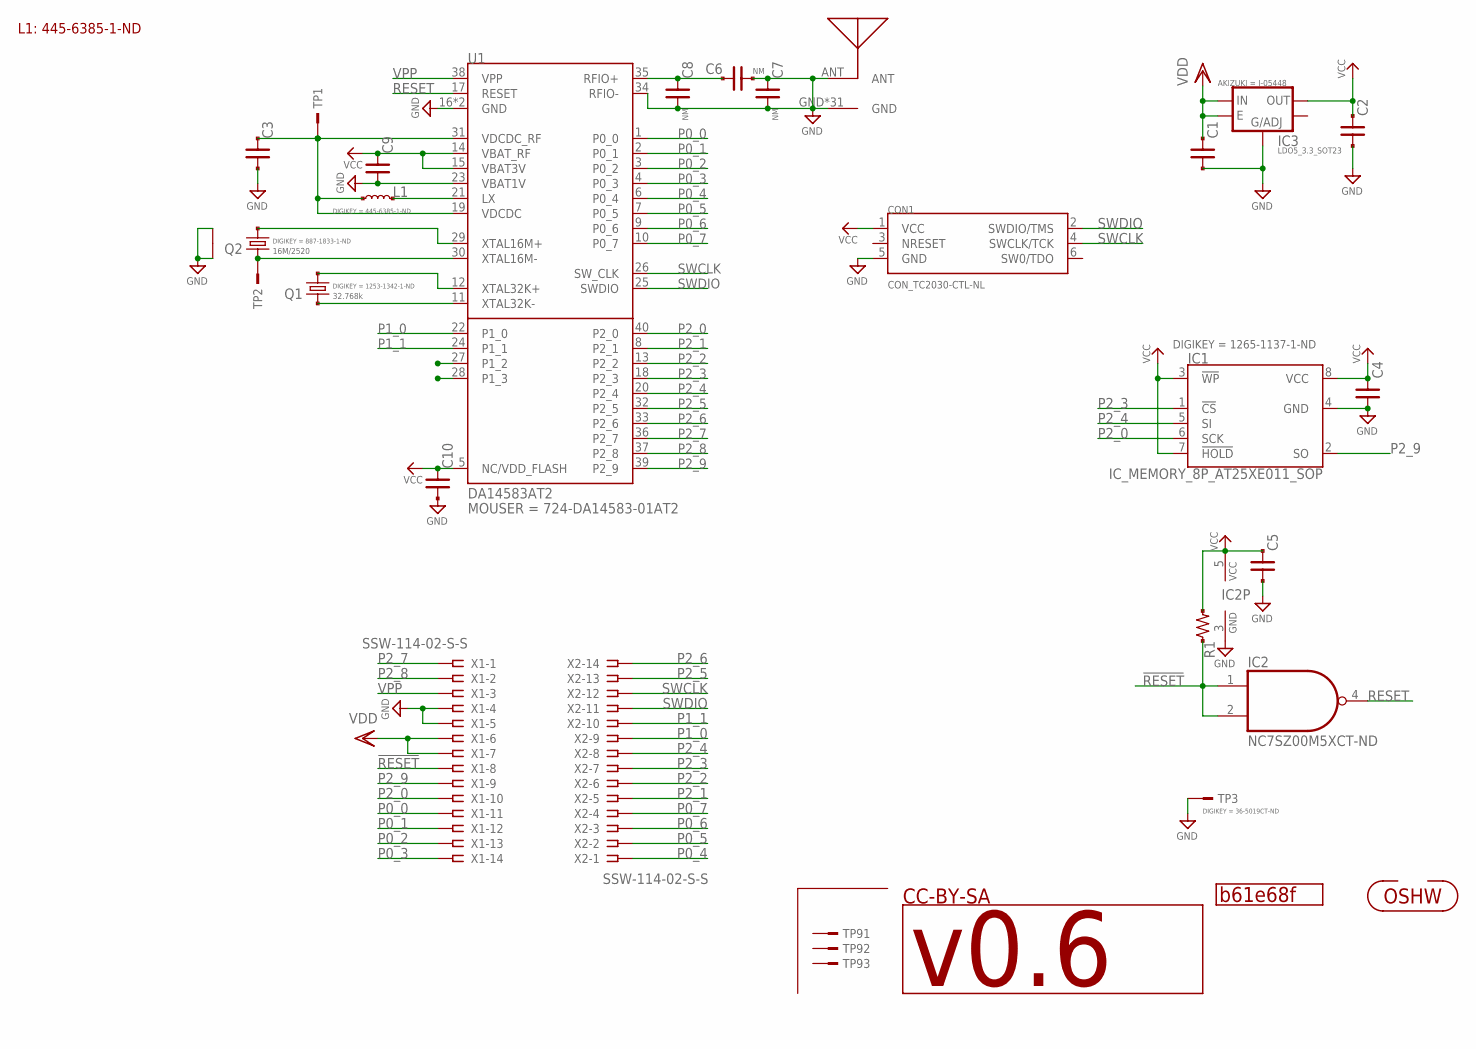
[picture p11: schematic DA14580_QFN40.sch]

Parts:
C1, C2, C3, C9: C_SMD_1.0U_1005; C0402
C4, C5, C10: C_SMD_0.1U_1005; C0402
C6, C7, C8: NM; C0402
CON1: CON_TC2030-CTL-NL; CON_TC2030-IDC-NL
GIT1: b61e68f; GIT-REVISION
IC1: IC_MEMORY_8P_AT25XE011_SOP; IC_08_1.27_150MIL
IC2: NC7SZ00M5XCT-ND; SOT23-5
IC3: LDO5_3.3_SOT23; IC_05_0.95_50MIL
ICON1: v0.6; ICON_REVISION1.2
L1: INDUCTOR_2.2U_1608; L_1608
Q1: 32.768k; CR_2125
Q2: 16M/2520; CLOCK_2520
R1: R_US_10K_1005; C0402
TP1, TP2: TESTPAD; TP06RECT
TP3: TESTPAD_4020; TP_4020
TP91, TP92, TP93: TESTPAD_F; FIDUCIAL
U1: DA14583AT2; QFN40_0.4P5.0X5.0
U$1: ANT_IFA; ANT_IFA_V2
U$2: ICON_OSHW
X1, X2: SSW-114-02-S-S

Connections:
!RESET!: IC2.1 (I0), IC2.2 (I1), R1.1, X1.8
GND: C1.2, C2.2, C3.2, C4.2, C5.2, C6.2, C7.1, C7.2, C8.2, C9.2, C10.2, CON1.5 (GND), IC1.4 (GND), IC2.3 (GND), IC3.2 (ADJ), Q2.2, Q2.4, TP3.TP, U1.16 (GND), U1.23 (VBAT1V), U1.34 (RFIO-), U1.BP (GND), U$1.ANT, U$1.GND, U$1.GND@1 (GND), U$1.GND@2 (GND), U$1.GND@3 (GND), U$1.GND@4 (GND), U$1.GND@5 (GND), U$1.GND@6 (GND), U$1.GND@7 (GND), U$1.GND@8 (GND), U$1.GND@9 (GND), U$1.GND@10 (GND), U$1.GND@11 (GND), U$1.GND@12 (GND), U$1.GND@13 (GND), U$1.GND@14 (GND), U$1.GND@15 (GND), U$1.GND@16 (GND), U$1.GND@17 (GND), U$1.GND@18 (GND), U$1.GND@19 (GND), U$1.GND@20 (GND), U$1.GND@21 (GND), U$1.GND@22 (GND), U$1.GND@23 (GND), U$1.GND@24 (GND), U$1.GND@25 (GND), U$1.GND@26 (GND), U$1.GND@27 (GND), U$1.GND@28 (GND), U$1.GND@29 (GND), U$1.GND@30 (GND), X1.4, X1.5
unnamed: C6.1, C8.1, U1.35 (RFIO+)
unnamed: L1.2, U1.21 (LX)
unnamed: C3.1, L1.1, TP1.TP, U1.19 (VDCDC), U1.31 (VDCDC_RF)
unnamed: Q1.1, U1.12 (XTAL32K+)
unnamed: Q1.2, U1.11 (XTAL32K-)
unnamed: Q2.1, U1.29 (XTAL16M+)
unnamed: Q2.3 (2), TP2.TP, U1.30 (XTAL16M-)
P0_0: U1.1 (P0_0), X1.11
P0_1: U1.2 (P0_1), X1.12
P0_2: U1.3 (P0_2), X1.13
P0_3: U1.4 (P0_3), X1.14
P0_4: U1.6 (P0_4), X2.1
P0_5: U1.7 (P0_5), X2.2
P0_6: U1.9 (P0_6), X2.3
P0_7: U1.10 (P0_7), X2.4
P1_0: U1.22 (P1_0), X2.9
P1_1: U1.24 (P1_1), X2.10
P1_2: U1.27 (P1_2)
P1_3: U1.28 (P1_3)
P2_0: IC1.6 (SCK), U1.40 (P2_0), X1.10
P2_1: U1.8 (P2_1), X2.5
P2_2: U1.13 (P2_2), X2.6
P2_3: IC1.1 (!CS), U1.18 (P2_3), X2.7
P2_4: IC1.5 (SI), U1.20 (P2_4), X2.8
P2_5: U1.32 (P2_5), X2.13
P2_6: U1.33 (P2_6), X2.14
P2_7: U1.36 (P2_7), X1.1
P2_8: U1.37 (P2_8), X1.2
P2_9: IC1.2 (SO), U1.39 (P2_9), X1.9
RESET: IC2.4 (O), U1.17 (RESET)
SWCLK: CON1.4 (SWCLK/TCK), U1.26 (SW_CLK), X2.12
SWDIO: CON1.2 (SWDIO/TMS), U1.25 (SWDIO), X2.11
VCC: C2.1, C4.1, C5.1, C9.1, C10.1, CON1.1 (VCC), IC1.3 (!WP), IC1.7 (!HOLD), IC1.8 (VCC), IC2.5 (VCC), IC3.5 (OUT), R1.2, U1.5 (NC/VDD_FLASH), U1.14 (VBAT_RF), U1.15 (VBAT3V)
VDD: C1.1, IC3.1 (IN), IC3.3 (E), X1.6, X1.7
VPP: U1.38 (VPP), X1.3

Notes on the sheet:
L1: 445-6385-1-ND
CC-BY-SA

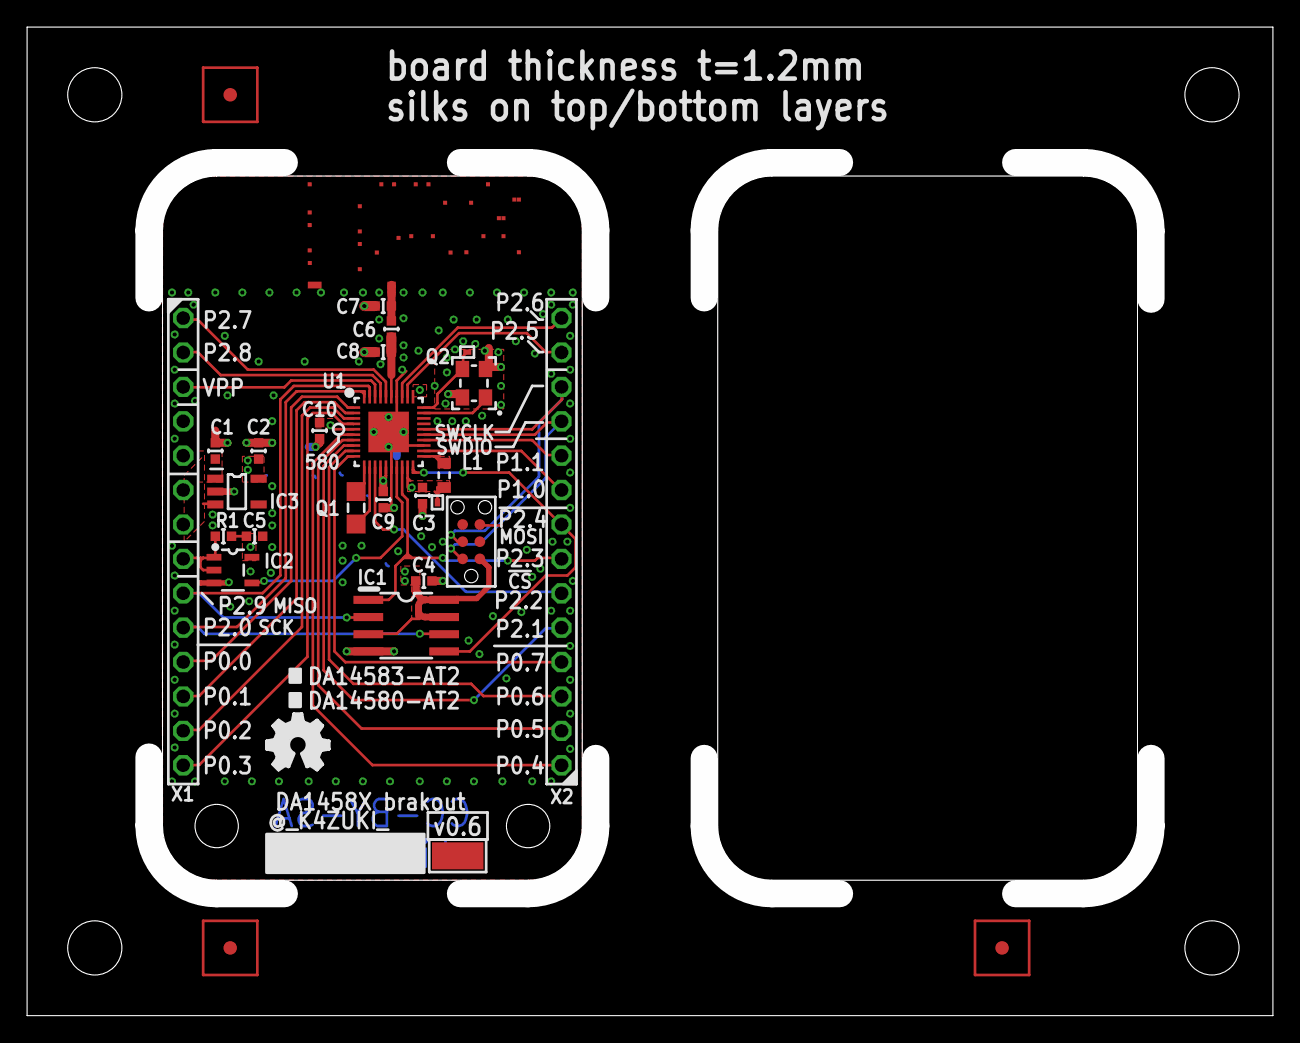
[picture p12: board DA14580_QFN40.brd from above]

Board: 2 copper layers, 92.0 x 73.0 mm, 31 parts (0 on the bottom side), 35 nets.

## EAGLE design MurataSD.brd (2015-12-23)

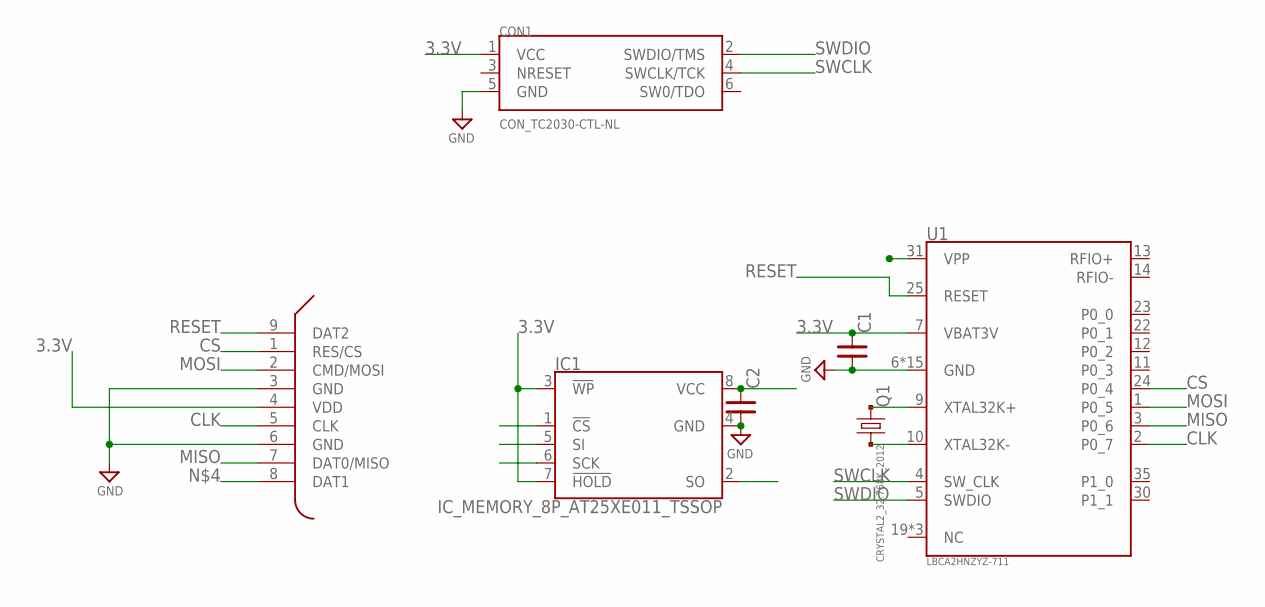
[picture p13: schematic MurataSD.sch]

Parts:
C1, C2: C_SMD_0.1U_1005; C0402
CON1: CON_TC2030-CTL-NL; CON_TC2030-IDC-NL
IC1: IC_MEMORY_8P_AT25XE011_TSSOP; IC_08_0.65_160MIL
Q1: CRYSTAL2_32.768K_2012; CR_2125
U1: LBCA2HNZYZ-711; IC_MURATA_LBCA2HNZYZ-711
U2: BOARD_MMC

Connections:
3.3V: C1.1, C2.1, CON1.1 (VCC), IC1.3 (!WP), IC1.7 (!HOLD), IC1.8 (VCC), U1.7 (VBAT3V), U2.4 (VDD)
CLK: IC1.6 (SCK), U1.2 (P0_7), U2.5 (CLK)
CS: IC1.1 (!CS), U1.24 (P0_4), U2.1 (RES/CS)
GND: C1.2, C2.2, CON1.5 (GND), IC1.4 (GND), U1.6 (GND), U1.8 (GND), U1.15 (GND), U1.16 (GND), U1.17 (GND), U1.18 (GND), U1.20 (GND), U1.21 (GND), U1.26 (GND), U1.27 (GND), U1.28 (GND), U1.29 (GND), U1.32 (GND), U1.33 (GND), U1.34 (GND), U2.3 (GND), U2.6 (GND)
MISO: IC1.2 (SO), U1.3 (P0_6), U2.7 (DAT0/MISO)
MOSI: IC1.5 (SI), U1.1 (P0_5), U2.2 (CMD/MOSI)
unnamed: Q1.1, U1.9 (XTAL32K+)
unnamed: Q1.2, U1.10 (XTAL32K-)
RESET: U1.25 (RESET), U2.9 (DAT2)
SWCLK: CON1.4 (SWCLK/TCK), U1.4 (SW_CLK)
SWDIO: CON1.2 (SWDIO/TMS), U1.5 (SWDIO)

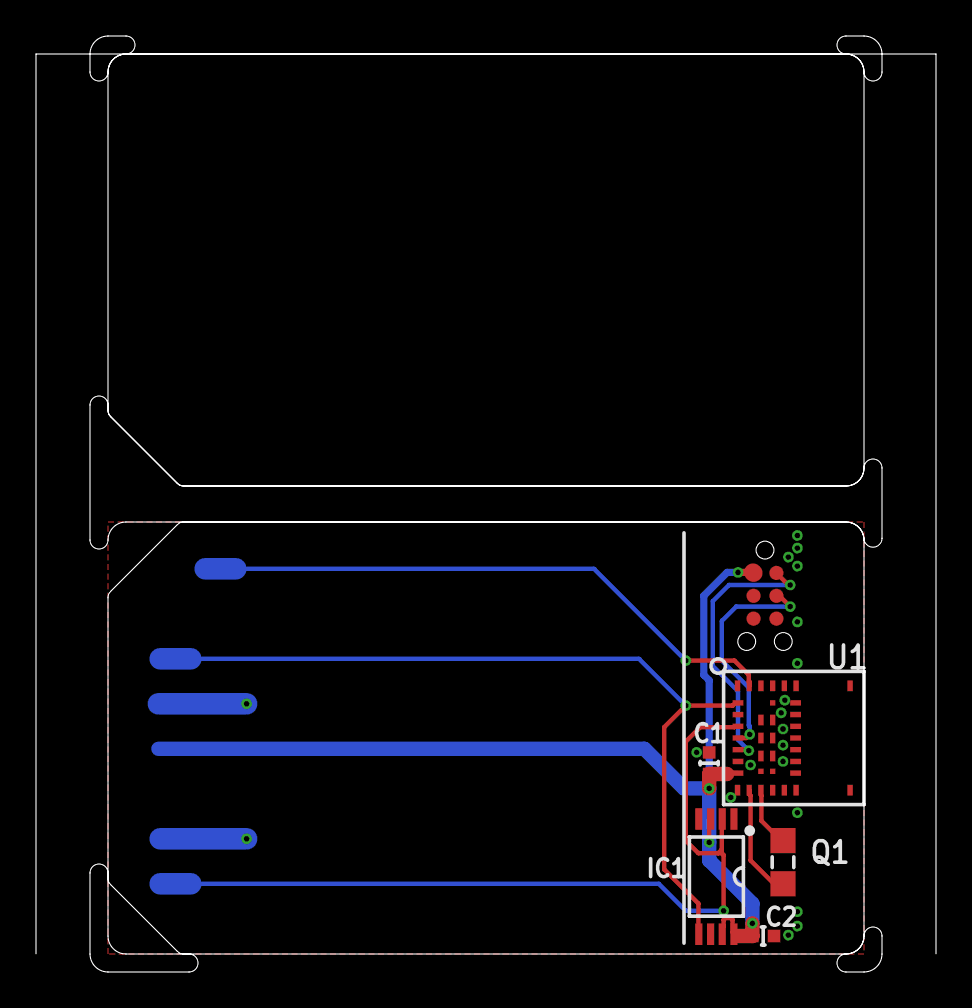
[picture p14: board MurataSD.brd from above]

Board: 2 copper layers, 44.0 x 52.0 mm, 7 parts (0 on the bottom side), 11 nets.

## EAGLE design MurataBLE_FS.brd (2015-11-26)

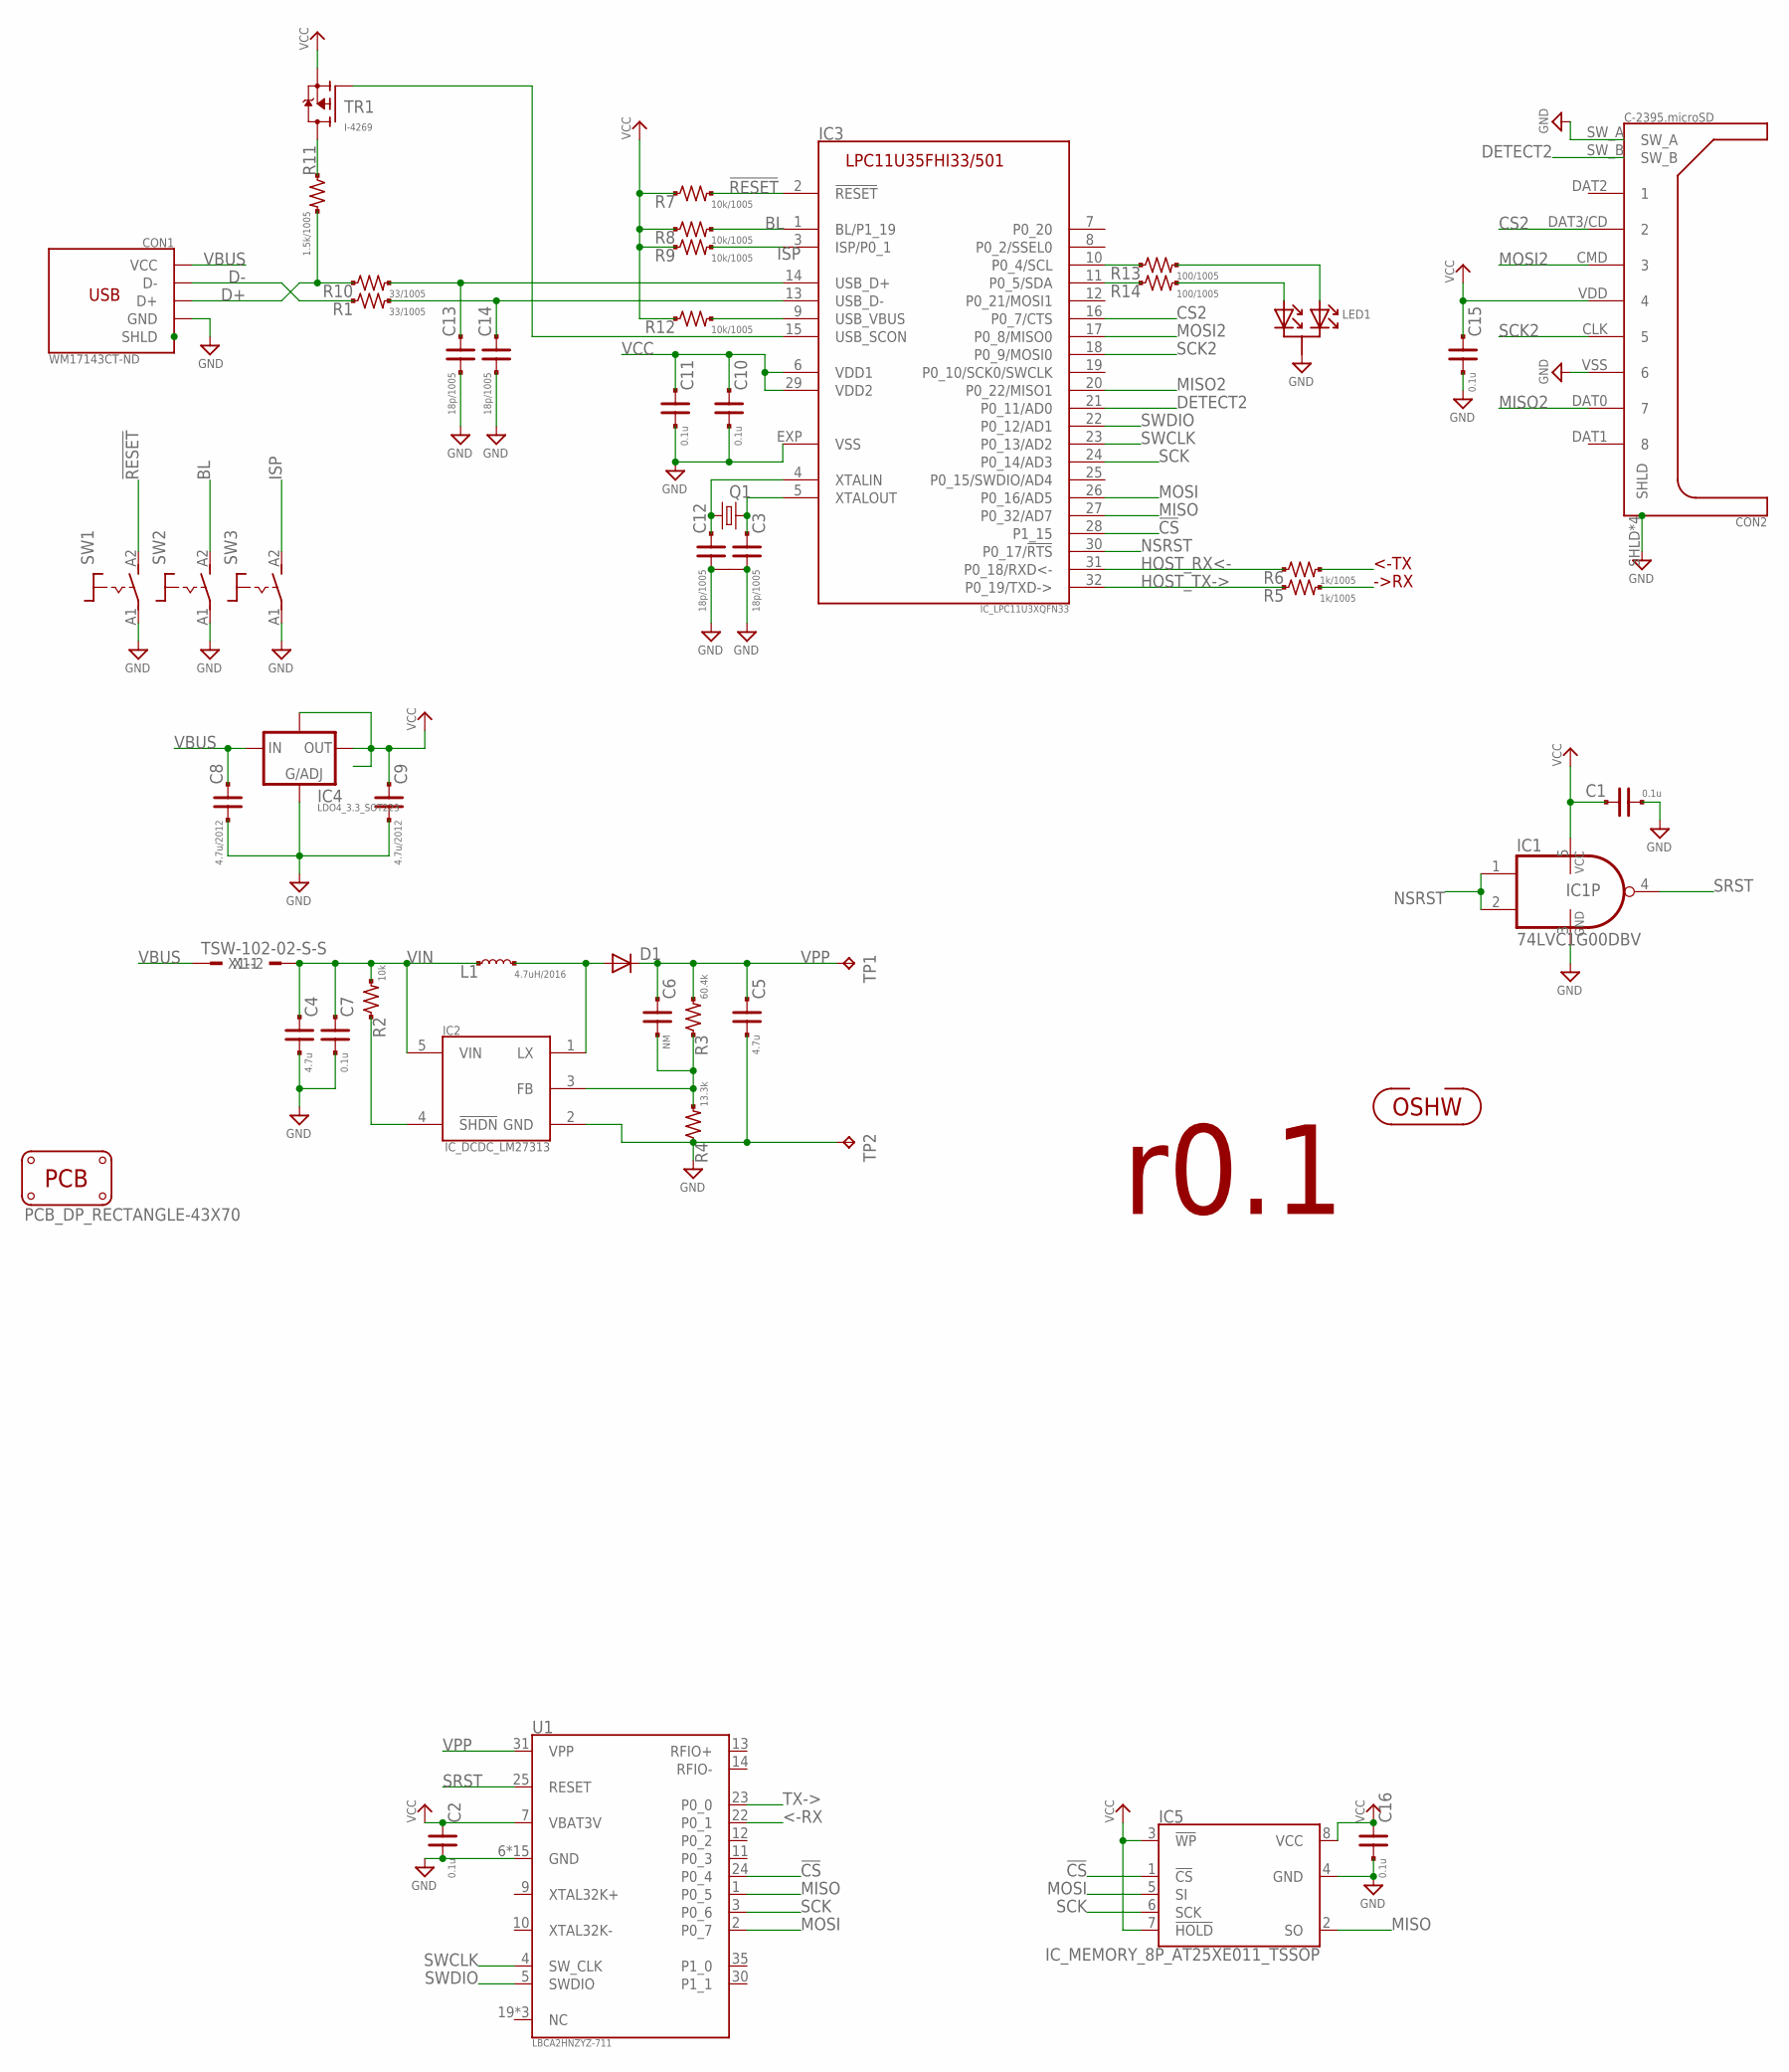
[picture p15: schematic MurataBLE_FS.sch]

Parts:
C1, C2, C10, C11, C16: 0.1u; C0402
C3, C12, C13, C14: 18p/1005; C0402
C4, C5: 4.7u; CR_2125
C6: NM; CR_1608
C7, C15: 0.1u; CR_1608
C8, C9: 4.7u/2012; CR_2125
CON1: WM17143CT-ND; CON_USB_47589-0001MOLEX
CON2: C-2395.microSD; CON_MICROSD_C2395
D1: DIODE_SMALL; DIODE_2125
IC1: 74LVC1G00DBV; SOT23-5
IC2: IC_DCDC_LM27313; IC_05_0.95_50MIL
IC3: IC_LPC11U3XQFN33; HVQFN33
IC4: LDO4_3.3_SOT223; IC_SOT223
IC5: IC_MEMORY_8P_AT25XE011_TSSOP; IC_08_0.65_160MIL
L1: 4.7uH/2016; L_2016
LED1: LED_1SEG_A2K1; SOT95P300X140-3N
PCB1: PCB_DP_RECTANGLE-43X70; DP7043_V1
Q1: CRYSTAL4_12M_3225; CLOCK_3225
R1, R10: 33/1005; C0402
R2: 10k; R_1608_PADPAD
R3: 60.4k; R_1608_PADPAD
R4: 13.3k; R_1608_PADPAD
R5, R6: 1k/1005; C0402
R7, R8, R9, R12: 10k/1005; C0402
R11: 1.5k/1005; C0402
R13, R14: 100/1005; C0402
SW1, SW3: TACTSW2_BK_P807X; SW_TACTSW_P8073
SW2: TACTSW2_WH_P807X; SW_TACTSW_P8073
TP1: P7592; P1-13
TP2: P7591; P1-13
TR1: I-4269; SOT95P300X140-3N
U1: LBCA2HNZYZ-711; IC_MURATA_LBCA2HNZYZ-711
U$1: ICON_OSHW
X1: TSW-102-02-S-S

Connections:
!CS!: IC3.28 (P1_15), IC5.1 (!CS), U1.24 (P0_4)
!RESET!: IC3.2 (!RESET!), R7.2, SW1.A2 (S)
<-RX: R5.2, U1.22 (P0_1)
BL: IC3.1 (BL/P1_19), R8.2, SW2.A2 (S)
CS2: CON2.DAT3/CD (2), IC3.16 (P0_7/CTS)
D+: CON1.3 (D+), R10.1, R11.2
D-: CON1.2 (D-), R1.1
DETECT2: CON2.SW_B, IC3.21 (P0_11/AD0)
GND: C1.2, C2.2, C3.2, C4.2, C5.2, C7.2, C8.2, C9.2, C10.2, C11.2, C12.2, C13.2, C14.2, C15.2, C16.2, CON1.5 (GND), CON2.SHLD, CON2.SHLD@2 (SHLD), CON2.SHLD@3 (SHLD), CON2.SHLD@4 (SHLD), CON2.SW_A, CON2.VSS (6), IC1.3 (GND), IC2.2 (GND), IC3.EXP (VSS), IC4.1 (ADJ), IC5.4 (GND), LED1.3 (K1), Q1.2, Q1.4, R4.1, SW1.A1, SW2.A1, SW3.A1, TP2.TP, U1.6 (GND), U1.8 (GND), U1.15 (GND), U1.16 (GND), U1.17 (GND), U1.18 (GND), U1.20 (GND), U1.21 (GND), U1.26 (GND), U1.27 (GND), U1.28 (GND), U1.29 (GND), U1.32 (GND), U1.33 (GND), U1.34 (GND)
HOST_RX<-: IC3.31 (P0_18/RXD<-), R6.1
HOST_TX->: IC3.32 (P0_19/TXD->), R5.1
ISP: IC3.3 (ISP/P0_1), R9.2, SW3.A2 (S)
MISO: IC3.27 (P0_32/AD7), IC5.2 (SO), U1.1 (P0_5)
MISO2: CON2.DAT0 (7), IC3.20 (P0_22/MISO1)
MOSI: IC3.26 (P0_16/AD5), IC5.5 (SI), U1.2 (P0_7)
MOSI2: CON2.CMD (3), IC3.17 (P0_8/MISO0)
unnamed: R11.1, TR1.3 (D)
unnamed: IC3.10 (P0_4/SCL), R13.1
unnamed: CON1.SHD (SHLD), CON1.SHD$1 (SHLD), CON1.SHD$2 (SHLD), CON1.SHD$3 (SHLD), CON1.SHD$4 (SHLD), CON1.SHD$5 (SHLD), CON1.SHD$6 (SHLD), CON1.SHD$7 (SHLD)
unnamed: C12.1, IC3.4 (XTALIN), Q1.1
unnamed: IC3.11 (P0_5/SDA), R14.1
unnamed: D1.A, IC2.1 (LX), L1.2
unnamed: IC2.4 (!SHDN!), R2.1
unnamed: LED1.2 (A2), R13.2
unnamed: C6.2, IC2.3 (FB), R3.1, R4.2
unnamed: C3.1, IC3.5 (XTALOUT), Q1.3 (2)
unnamed: IC3.15 (USB_SCON), TR1.1 (G)
unnamed: IC3.9 (USB_VBUS), R12.2
unnamed: LED1.1 (A1), R14.2
unnamed: C13.1, IC3.14 (USB_D+), R10.2
unnamed: C14.1, IC3.13 (USB_D-), R1.2
NSRST: IC1.1 (I0), IC1.2 (I1), IC3.30 (P0_17/!RTS!)
SCK: IC3.24 (P0_14/AD3), IC5.6 (SCK), U1.3 (P0_6)
SCK2: CON2.CLK (5), IC3.18 (P0_9/MOSI0)
SRST: IC1.4 (O), U1.25 (RESET)
SWCLK: IC3.23 (P0_13/AD2), U1.4 (SW_CLK)
SWDIO: IC3.22 (P0_12/AD1), U1.5 (SWDIO)
TX->: R6.2, U1.23 (P0_0)
VBUS: C8.1, CON1.1 (VCC), IC4.3 (IN), X1.1
VCC: C1.1, C2.1, C9.1, C10.1, C11.1, C15.1, C16.1, CON2.VDD (4), IC1.5 (VCC), IC3.6 (VDD1), IC3.29 (VDD2), IC4.2 (OUT), IC4.4 (OUT/EN/NC), IC5.3 (!WP), IC5.7 (!HOLD), IC5.8 (VCC), R7.1, R8.1, R9.1, R12.1, TR1.2 (S), U1.7 (VBAT3V)
VIN: C4.1, C7.1, IC2.5 (VIN), L1.1, R2.2, X1.2
VPP: C5.1, C6.1, D1.K (C), R3.2, TP1.TP, U1.31 (VPP)

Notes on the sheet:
r0.1
->RX
<-TX


Board: 2 copper layers, 90.0 x 63.0 mm, 51 parts (0 on the bottom side), 42 nets.

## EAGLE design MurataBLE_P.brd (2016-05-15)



Board: 2 copper layers, 90.0 x 70.0 mm, 113 parts (8 on the bottom side), 94 nets.

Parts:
C1, C3, C15, C16: 1u/1608; CR_1608
C2, C4, C5, C6, C11, C12, C13, C14, C19, C20, C21, C24, C25, C26: 0.1u/1005; C0402
C7, C8, C9, C10, C17, C18, C22, C23: 18p/1005; C0402
CON1, CON2: 47589-0001; CON_USB_47589-0001MOLEX
GIT1, GIT2: aef7891; GIT-REVISION
IC1, IC10: DFN80P410X410_8N
IC2, IC8: LPC11U35_QFN33; HVQFN33
IC3, IC9: NC7SZ00; SOT95P280X145-5N
IC4, IC6: AT25DN512C; IC_08_1.27_150MIL
IC5, IC7: AT25XE011; IC_08_1.27_150MIL
ICON1, ICON3: r0.4; ICON_REVISION1.2
ICON2, ICON4: NC; ICON_OSHW
LED1, LED2, LED3, LED4: LED_3SEG; LED_3SEG_SMD
P1, P2, P3, P4, P5, P6, P7, P8: NC; PCB_CORNER_NH
Q1, Q3: 32.768K/2012; CR_2125
Q2, Q4: 12M/3225; CLOCK_3225
R1, R6, R7, R8, R9, R14, R15, R19, R22, R23, R24, R25, R32, R33: 10k/1005; C0402
R2, R3, R20, R21: 33/1005; C0402
R4, R5, R11, R16, R17, R18, R27, R28, R29, R34, R35, R36: 1k/1005; C0402
R10, R26: 1.5k/1005; C0402
R12, R13, R30, R31: NC; R0402SHORT
SW1, SW2, SW3, SW4, SW5, SW6: FSM2JMTR; SW_TACTSW_FSM2JMTR
TP100, TP101, TP102: NC; FIDUCIAL
TR1, TR2: BSS84; SOT95P300X140-3N
U1, U2: LBCA2HNZYZ; IC_MURATA_LBCA2HNZYZ-711
X1, X2, X3, X4: TSW-114-02-S-S; TSW-114-07-F-S

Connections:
3.3V: C2.1, C3.1, C4.1, C5.1, C6.1, C11.1, C12.1, IC1.5, IC1.6, IC1.7, IC1.EP, IC2.6, IC2.29, IC3.5, IC4.3, IC4.7, IC4.8, IC5.3, IC5.7, IC5.8, LED1.4, LED1.5, LED1.6, R1.1, R6.1, R7.1, R8.1, R9.1, R14.2, R15.2, TR1.2, U1.7, X2.1
3.3V1: C14.1, C16.1, C19.1, C20.1, C21.1, C24.1, C25.1, IC6.3, IC6.7, IC6.8, IC7.3, IC7.7, IC7.8, IC8.6, IC8.29, IC9.5, IC10.5, IC10.6, IC10.7, IC10.EP, LED3.4, LED3.5, LED3.6, R19.1, R22.1, R23.1, R24.1, R25.1, R32.2, R33.2, TR2.2, U2.7, X4.1
580.P0_0: LED2.4, R12.3, U1.23, X1.5
580.P0_1: LED2.5, R13.3, U1.22, X1.4
580.P0_2: IC2.12, IC5.1, U1.12, X1.11
580.P0_3: IC2.16, IC5.2, U1.11, X1.10
580.P0_4: U1.24, X1.6
580.P0_5: U1.1, X1.7
580.P0_6: IC2.17, IC5.6, U1.3, X1.9
580.P0_7: IC2.18, IC5.5, U1.2, X1.8
580.P0_8: U2.1, X3.7
580.P0_9: IC7.6, IC8.17, U2.3, X3.9
580.P0_10: IC7.5, IC8.18, U2.2, X3.8
580.P0_11: IC7.1, IC8.12, U2.12, X3.11
580.P0_12: IC7.2, IC8.16, U2.11, X3.10
580.P0_13: U2.24, X3.6
580.P0_14: LED4.4, R30.3, U2.23, X3.5
580.P0_15: LED4.5, R31.3, U2.22, X3.4
580.P1_0: LED2.6, U1.35, X1.3
580.P1_1: U1.30, X1.12
580.P1_2: LED4.6, U2.35, X3.3
580.P1_3: U2.30, X3.12
!RESET!: IC2.2, R9.2, SW1.2
!RESET!1: IC8.2, R25.2, SW4.2
FB_BL: IC2.1, R7.2, SW3.2
FB_BL1: IC8.1, R23.2, SW6.2
FB_ISP: IC2.3, R8.2, SW2.2
FB_ISP1: IC8.3, R24.2, SW5.2
GND: C1.2, C2.2, C3.2, C4.2, C5.2, C6.2, C7.2, C8.2, C9.2, C10.2, C11.2, C12.2, C13.2, CON1.5, CON1.SHD, CON1.SHD$1, CON1.SHD$2, CON1.SHD$3, CON1.SHD$4, CON1.SHD$5, CON1.SHD$6, CON1.SHD$7, IC1.1, IC2.EXP, IC3.3, IC4.4, IC5.4, Q2.2, Q2.4, R16.2, R17.2, R18.2, SW1.1, SW2.1, SW3.1, U1.6, U1.8, U1.15, U1.16, U1.17, U1.18, U1.20, U1.21, U1.26, U1.27, U1.28, U1.29, U1.32, U1.33, U1.34, X1.13
GND1: C14.2, C15.2, C16.2, C17.2, C18.2, C19.2, C20.2, C21.2, C22.2, C23.2, C24.2, C25.2, C26.2, CON2.5, CON2.SHD, CON2.SHD$1, CON2.SHD$2, CON2.SHD$3, CON2.SHD$4, CON2.SHD$5, CON2.SHD$6, CON2.SHD$7, IC6.4, IC7.4, IC8.EXP, IC9.3, IC10.1, Q4.2, Q4.4, R34.2, R35.2, R36.2, SW4.1, SW5.1, SW6.1, U2.6, U2.8, U2.15, U2.16, U2.17, U2.18, U2.20, U2.21, U2.26, U2.27, U2.28, U2.29, U2.32, U2.33, U2.34, X3.13
unnamed: Q1.1, U1.9
unnamed: Q1.2, U1.10
unnamed: C13.1, IC2.9, R6.2
unnamed: Q3.1, U2.9
unnamed: R10.1, TR1.3
unnamed: IC2.15, TR1.1
unnamed: IC2.7, R4.1
unnamed: IC2.10, R5.1
unnamed: IC2.11, R11.1
unnamed: LED1.1, R11.2
unnamed: LED1.2, R5.2
unnamed: LED1.3, R4.2
unnamed: LED2.3, R18.1
unnamed: LED2.2, R17.1
unnamed: LED2.1, R16.1
unnamed: Q3.2, U2.10
unnamed: C8.1, IC2.4, Q2.1
unnamed: C9.1, IC2.5, Q2.3
unnamed: C7.1, IC2.14, R3.2
unnamed: CON1.3, R3.1, R10.2
unnamed: CON1.2, R2.1
unnamed: C17.1, IC8.4, Q4.1
unnamed: C10.1, IC2.13, R2.2
unnamed: C18.1, IC8.5, Q4.3
unnamed: CON2.3, R21.1, R26.2
unnamed: CON2.2, R20.1
unnamed: C22.1, IC8.14, R21.2
unnamed: C23.1, IC8.13, R20.2
unnamed: C26.1, IC8.9, R22.2
unnamed: R26.1, TR2.3
unnamed: IC8.15, TR2.1
unnamed: IC8.7, R27.1
unnamed: IC8.10, R28.1
unnamed: IC8.11, R29.1
unnamed: LED3.2, R28.2
unnamed: LED3.1, R29.2
unnamed: LED3.3, R27.2
unnamed: LED4.3, R36.1
unnamed: LED4.2, R35.1
unnamed: LED4.1, R34.1
NSRST: IC2.8, IC3.1, IC3.2, R1.2
NSRST1: IC8.8, IC9.1, IC9.2, R19.2
P0_1: IC6.2, IC8.27
P0_2: IC6.5, IC8.26
P0_3: IC6.6, IC8.25
P0_15: IC2.25, IC4.6
P0_16: IC2.26, IC4.5
P0_32: IC2.27, IC4.2
P1_1: IC6.1, IC8.28
P1_15: IC2.28, IC4.1
RESET: IC3.4, U1.25
RESET1: IC9.4, U2.25
SWCLK: IC2.23, R14.1, U1.4, X1.1
SWCLK1: IC8.23, R32.1, U2.4, X3.1
SWDIO: IC2.24, R15.1, U1.5, X1.2
SWDIO1: IC8.24, R33.1, U2.5, X3.2
TGT_RX: IC2.32, R13.1, R13.2
TGT_RX1: IC8.32, R31.1, R31.2
TGT_TX: IC2.31, R12.1, R12.2
TGT_TX1: IC8.31, R30.1, R30.2
VPP: U1.31, X1.14
VPP2: U2.31, X3.14
VUSB: C1.1, CON1.1, IC1.2, IC1.3, IC1.4
VUSB1: C15.1, CON2.1, IC10.2, IC10.3, IC10.4

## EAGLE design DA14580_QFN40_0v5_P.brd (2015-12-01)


Board: 2 copper layers, 92.0 x 73.0 mm, 55 parts (0 on the bottom side), 70 nets.

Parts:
C1, C2, C3, C4, C5, C9, C10, C11, C12, C13, C14, C15, C19, C20: C0402
C6, C7, C8, C16, C17, C18: NM; C0402
CON1, CON2: CON_TC2030-CTL-NL; CON_TC2030-IDC-NL
IC1, IC4: IC_MEMORY_8P_AT25XE011_SOP; IC_08_1.27_150MIL
IC2, IC6: NC7SZ00M5XCT-ND; SOT23-5
IC3, IC5: LDO5_3.3_SOT23; IC_05_0.95_50MIL
L1, L2: L_1608
Q1, Q3: 32.768k; CRYSTAL_FC-135
Q2, Q4: 16M/2520; CLOCK_2520
R1, R2: C0402
TP1, TP2, TP5, TP6: TESTPAD; TP06RECT
TP3, TP4: TPPAD1-13; P1-13
TP91, TP92, TP93: TESTPAD_F; FIDUCIAL
U1, U2: DA14583AT2; QFN40_0.4P5.0X5.0
U$1, U$3: ANT_IFA; ANT_IFA_V2
U$2, U$4: ICON_OSHW
X1, X2, X3, X4: SSW-114-02-S-S

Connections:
!RESET!: IC2.1, IC2.2, R1.1, X1.8
!RESET!1: IC6.1, IC6.2, R2.1, X3.8
GND: C1.2, C2.2, C3.2, C4.2, C5.2, C6.2, C7.1, C7.2, C8.2, C9.2, C10.2, CON1.5, IC1.4, IC2.3, IC3.2, Q2.2, Q2.4, TP3.TP, U1.16, U1.23, U1.34, U1.BP, U$1.ANT, U$1.GND, U$1.GND@1, U$1.GND@2, U$1.GND@3, U$1.GND@4, U$1.GND@5, U$1.GND@6, U$1.GND@7, U$1.GND@8, U$1.GND@9, U$1.GND@10, U$1.GND@11, U$1.GND@12, U$1.GND@13, U$1.GND@14, U$1.GND@15, U$1.GND@16, U$1.GND@17, U$1.GND@18, U$1.GND@19, U$1.GND@20, U$1.GND@21, U$1.GND@22, U$1.GND@23, U$1.GND@24, U$1.GND@25, U$1.GND@26, U$1.GND@27, U$1.GND@28, U$1.GND@29, U$1.GND@30, X1.4, X1.5
GND1: C11.2, C12.2, C13.2, C14.2, C15.2, C16.2, C17.1, C17.2, C18.2, C19.2, C20.2, CON2.5, IC4.4, IC5.2, IC6.3, Q4.2, Q4.4, TP4.TP, U2.16, U2.23, U2.34, U2.BP, U$3.ANT, U$3.GND, U$3.GND@1, U$3.GND@2, U$3.GND@3, U$3.GND@4, U$3.GND@5, U$3.GND@6, U$3.GND@7, U$3.GND@8, U$3.GND@9, U$3.GND@10, U$3.GND@11, U$3.GND@12, U$3.GND@13, U$3.GND@14, U$3.GND@15, U$3.GND@16, U$3.GND@17, U$3.GND@18, U$3.GND@19, U$3.GND@20, U$3.GND@21, U$3.GND@22, U$3.GND@23, U$3.GND@24, U$3.GND@25, U$3.GND@26, U$3.GND@27, U$3.GND@28, U$3.GND@29, U$3.GND@30, X3.4, X3.5
unnamed: C6.1, C8.1, U1.35
unnamed: Q3.1, U2.12
unnamed: Q3.2, U2.11
unnamed: Q4.1, U2.29
unnamed: Q4.3, TP6.TP, U2.30
unnamed: L1.2, U1.21
unnamed: L2.2, U2.21
unnamed: C13.1, L2.1, TP5.TP, U2.19, U2.31
unnamed: C3.1, L1.1, TP1.TP, U1.19, U1.31
unnamed: C16.1, C18.1, U2.35
unnamed: Q1.1, U1.12
unnamed: Q1.2, U1.11
unnamed: Q2.1, U1.29
unnamed: Q2.3, TP2.TP, U1.30
P0_0: U1.1, X1.11
P0_1: U1.2, X1.12
P0_2: U1.3, X1.13
P0_3: U1.4, X1.14
P0_4: U1.6, X2.1
P0_5: U1.7, X2.2
P0_6: U1.9, X2.3
P0_7: U1.10, X2.4
P0_8: U2.1, X3.11
P0_9: U2.2, X3.12
P0_10: U2.3, X3.13
P0_11: U2.4, X3.14
P0_12: U2.7, X4.2
P0_13: U2.6, X4.1
P0_14: U2.10, X4.4
P0_15: U2.9, X4.3
P1_0: U1.22, X2.9
P1_1: U1.24, X2.10
P1_4: U2.22, X4.9
P1_5: U2.24, X4.10
P2_0: IC1.6, U1.40, X1.10
P2_1: U1.8, X2.5
P2_2: U1.13, X2.6
P2_3: IC1.1, U1.18, X2.7
P2_4: IC1.5, U1.20, X2.8
P2_5: U1.32, X2.13
P2_6: U1.33, X2.14
P2_7: U1.36, X1.1
P2_8: U1.37, X1.2
P2_9: IC1.2, U1.39, X1.9
P2_10: IC4.1, U2.18, X4.7
P2_11: U2.13, X4.6
P2_12: IC4.6, U2.40, X3.10
P2_13: U2.8, X4.5
P2_14: U2.32, X4.13
P2_15: U2.33, X4.14
P2_16: IC4.2, U2.39, X3.9
P2_17: IC4.5, U2.20, X4.8
P2_18: U2.36, X3.1
P2_19: U2.37, X3.2
RESET: IC2.4, U1.17
RESET1: IC6.4, U2.17
SWCLK: CON1.4, U1.26, X2.12
SWCLK1: CON2.4, U2.26, X4.12
SWDIO: CON1.2, U1.25, X2.11
SWDIO1: CON2.2, U2.25, X4.11
VCC: C2.1, C4.1, C5.1, C9.1, C10.1, CON1.1, IC1.3, IC1.7, IC1.8, IC2.5, IC3.5, R1.2, U1.5, U1.14, U1.15
VCC1: C12.1, C14.1, C15.1, C19.1, C20.1, CON2.1, IC4.3, IC4.7, IC4.8, IC5.5, IC6.5, R2.2, U2.5, U2.14, U2.15
VDD: C1.1, IC3.1, IC3.3, X1.6, X1.7
VDD1: C11.1, IC5.1, IC5.3, X3.6, X3.7
VPP: U1.38, X1.3
VPP1: U2.38, X3.3

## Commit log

2015-03-02 [ NEW ] MurataBLE
    Murata LBCA2HNZYZ-711 module evaluation board
    [MurataBLE.brd, MurataBLE.sch]
2015-03-02 [ FIX ] GND plane
    [MurataBLE.brd]
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2015-03-02 [ BRD ] silk placement change
    Silk moved to north; related gerber change
    [MurataBLE.brd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]
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2015-03-04 [ FIX ] BOARD_MMC update
    [MurataSD.brd, MurataSD.sch]
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2015-03-06 [ FIX ] library update
    [MurataBLE.brd, MurataBLE.sch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]
2015-03-09 [ NEW ] MurataMicroSD IC_MURATA_LBCA2HNZYZ-711 on extended microSD card size PCB
    [MurataMicroSD.brd, MurataMicroSD.sch]
2015-03-09 [ NEW ] Gerbers(MurataMicroSD) Gerber files and gerbv file
    [MurataMicroSD_P.GBL, MurataMicroSD_P.GBO, MurataMicroSD_P.GBS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]
2015-03-09 [ NEW ] MurataMicroSD_P panelised version of MurataMicroSD.brd no schematic file
    [MurataMicroSD_P.brd]
2015-03-09 [ FIX ] GML/milling layer removed dimention layer in original file
2015-03-09 [ FIX ] milling layer
    [MurataMicroSD.brd]
2015-03-10 [ FIX ] MurataMicroSD
    add via for GND
    [MurataMicroSD.brd]
2015-03-11 [ FIX ] SCH change; library update myPCBlib: 385519d7d8f28a1be9991780ecc3cf499a6be8e2
    [MurataMicroSD.brd, MurataMicroSD.sch]
2015-03-11 [ FIX ] library update; trace; increase via myPCBlib: 0aa2107fd28665ba7552473a3fbc4a367f8d93bf
    [MurataMicroSD.brd, MurataMicroSD.sch]
2015-03-12 [ FIX ] MurataMicroSD
    airwire removed; tiny trace change
    [MurataMicroSD.brd]
2015-03-12 [ FIX ] MurataBLE
    small schema change
    library update
    increase GND via
    C2 moved
    [MurataBLE.brd, MurataBLE.sch]
2015-03-12 [ FIX ] fix trace, increase via
    [MurataBLE.brd, MurataBLE.sch]
2015-03-12 [ FIX ] BLE module placed on top
    other side of uSD contacts
    [MurataMicroSD.brd, MurataMicroSD.sch]
2015-03-12 [ uSD ] library update; inrease via; silk and bottom trace board name on top silk name and revision on bottom trace
    [MurataMicroSD.brd, MurataMicroSD.sch]
2015-03-12 [ uSD ][ GERBER ] panelise as update
    [MurataMicroSD_P.brd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]
2015-03-16 [ uSD_P ] extend outline
    PCBCART does not accept V-cut in outline below 55x55mm.
    extended to 60x60 plus add 2x V-cut lines
    [MurataMicroSD_P.brd]
2015-03-16 [ USB ][ FIX ] values of each components; replace PMOS to SOT23 package - R/C's value updated - replace to use SOT23 package MOS
    [MurataBLE.sch]
2015-03-16 [ USB ][ FIX ] Dimention; PMOS replace; silk on pinheader; via - demention changed to 60x55mm, vcut and milling added - PMOS replaced as schematic update - silk added on X1 pin header - via slight mo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
    [MurataBLE.brd]
2015-03-16 [ uSD ][ FIX ] extend board size to 60x60
    [MurataMicroSD.brd]
2015-03-17 [ USB ][ FIX ] library update
    [MurataBLE.brd, MurataBLE.sch]
2015-03-17 [ USB ] moved 2mm north; bigger milling; add silk
    [MurataBLE.brd]
2015-03-18 [ USB ] Q1 replace to CRYSTAL_FC-135
    [MurataBLE.brd, MurataBLE.sch]
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2015-03-18 [ FIX ] CLOCK_CRYSTAL;library update; part value
    [MurataBLE.brd, MurataBLE.sch]
2015-03-18 [ FIX ] texts
    [MurataBLE.brd]
2015-03-24 [ uSD ] fix as per library
    [MurataMicroSD.brd, MurataMicroSD.sch]
2015-03-30 [ FIX ][ USB ] milling layer
    [MurataBLE.brd]
2015-03-30 [ FIX ][ USB ] Merge
    [MurataBLE.brd]
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2015-03-30 [ uSD ] fix
    [MurataMicroSD.brd, MurataMicroSD.sch]
2015-03-31 [ uSD ] dimention lines
    moved dimention lines to avoid finished dimention size error after V-cut
    [MurataMicroSD.brd]
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2015-03-31 [ USB ] fix
    [MurataBLE.brd]
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2015-04-09 [ USB ][ FIX ] move R11 and Vdd
    [MurataBLE.brd]
2015-04-09 [ USB ][ FIX ] resistor value
    [MurataBLE.brd, MurataBLE.sch]
2015-04-09 [ FIX ] fixes as per update of mylib/LED_3SEG
    [MurataBLE.brd, MurataBLE.sch]
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2015-04-13 [ USB ] trace fix
    [MurataBLE.brd]
2015-04-13 [ USB ] trace fix
    VDD trace
    [MurataBLE.brd]
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2015-04-15 [ USB ][ FIX ] USB connection
    Fix USB line connection over R2,3,10, C7,10 and TR1
    referenced to AN11392,NXP
    [MurataBLE.brd, MurataBLE.sch]
2015-04-15 [ USB ][ BRD ] FIX
    [MurataBLE.brd]
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2015-04-16 [ USB ] extend pin header X1
    now ALL pins on header
    [MurataBLE.brd, MurataBLE.sch]
2015-04-16 [ USB ] update as library
    TP
    X1 Pin header
    [MurataBLE.brd, MurataBLE.sch]
2015-04-16 [ USB ][ BRD ] add jumpers
    added jumpers to keep net name on schematic
    [MurataBLE.brd]
2015-04-17 [ uSD ] panel outline/ P1_0/1 on pad
    - extend panel size
    - add 2.2mm drill
    - all but 32k xtal to be on pad
    - pads on top and bottom
    [MurataMicroSD.brd, MurataMicroSD.sch]
2015-04-17 [ uSD ][ FIX ] license stated
    [MurataMicroSD.brd, MurataMicroSD.sch]
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2015-04-20 [ USB ][ SCH ] test pads are connected
    [MurataBLE.brd, MurataBLE.sch]
2015-04-22 [ USB ] fix broken schematic link
    [MurataBLE.brd, MurataBLE.sch]
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2015-05-01 [ USB ] layer and silk fix
    [MurataBLE.brd]
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2015-05-08 [ USB ] milling fix; mylib also
    [MurataBLE.brd, MurataBLE.sch]
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2015-07-01 [ uSD ][ SCH ] added RESET node
    [MurataMicroSD.sch]
2015-07-22 [ FIX ] library update; add debug connector
    [MurataMicroSD.brd, MurataMicroSD.sch]
2015-07-23 [ FIX ] fiducial; v-cut is 0.8mm width
    [MurataBLE.brd]
2015-07-23 [ USB ][ SCH ] replace fiducial from 0.8mm to 2.0mm phi
    [MurataBLE.sch]
2015-08-06 [ USB ] shorter milling; R6 and IC1 silk move
    [MurataBLE.brd]
2015-08-06 [ uSD ] add 'Open Source Hardware' silk
    [MurataMicroSD.brd, MurataMicroSD.sch]
2015-08-07 [ uSD ] uSD pin 8 is replaced to Vpp
    [MurataMicroSD.brd, MurataMicroSD.sch]
2015-08-07 [ USB ] QFN33 paste mask change from library
    [MurataBLE.brd, MurataBLE.sch]
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2015-08-10 [ NEW ][ SCH ][ BRD ] MurataMicroMB
    [MurataMicroMB.brd, MurataMicroMB.sch]
2015-08-12 [ FIX ] add SPI ROM; board size extend; silk move
    [MurataMicroSD.brd, MurataMicroSD.sch]
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2015-08-13 [ uSD ] move silk; tiny trace fix
    [MurataMicroSD.brd, MurataMicroSD.sch]
2015-08-13 [ uSD ] debug connector moved; increase panel size
    [MurataMicroSD.brd]
2015-08-14 [ uSD ] OSHW icon replaced from library
    [MurataMicroSD.brd, MurataMicroSD.sch]
2015-08-17 [uSD][SCH] P0_4/P0_5 function name slight change
    P0_4/TXD->/MOSI
    P0_5/RXD<-/SCK
    [MurataMicroSD.sch]
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2015-08-18 [ FIX ] add DCDC converter(for Vpp), microSD sockets, switches, USB circuit
    [MurataMicroMB.brd, MurataMicroMB.sch]
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2015-08-29 [ MB ][ SCH ] connection to uSD sockets changed
    [MurataMicroMB.brd, MurataMicroMB.sch]
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2015-09-07 [ USB ] extend milling move v-cut 1mm north
    [MurataBLE.brd, MurataBLE.sch]
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2015-09-08 [ NEW ] MurataBLE_FS: BLE module,debugger,microSD and VPP generator on board
    [MurataBLE_FS.brd, MurataBLE_FS.sch]
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2015-09-18 [ MB ][ SCH ] values and details change
    [MurataMicroMB.brd, MurataMicroMB.sch]
2015-10-07 [ MB ] add R15/R16 function vs. pin number list
    [MurataMicroMB.brd, MurataMicroMB.sch]
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2015-10-22 [ MB ][ SCH ] R3/4 to use digikey number
    [MurataMicroMB.brd, MurataMicroMB.sch]
2015-10-27 [ MB ] layers fix
    [MurataMicroMB.brd]
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2015-10-31 [ NEW ] DA14580_QFN40_0v5.sch/.brd rename from _P to let _P indicate panelled version
    [DA14580_QFN40_0v5.brd, DA14580_QFN40_0v5.sch, DA14580_QFN40_0v5_P.sch]
2015-10-31 [ FIX ][ 58X ] update schematic with library
    [DA14580_QFN40_0v5.brd, DA14580_QFN40_0v5.sch, DA14580_QFN40_0v5_P.brd]
2015-10-31 [ NEW ][ 58X ] Gerber fies and a gerbv project file
    [DA14580_QFN40_0v5_P.GBL, DA14580_QFN40_0v5_P.GBO, DA14580_QFN40_0v5_P.GBS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]
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2015-11-10 [ MB ] R5/6/15/16 moved; add DETECT1/2 pin on schematic
    [MurataMicroMB.brd, MurataMicroMB.sch]
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2015-11-10 [ MB ] move SW1-3, BL shares IC1 with nSRST
    [MurataMicroMB.brd, MurataMicroMB.sch]
2015-11-10 [ MB ] pin1 to be used by TGT_RST; BL=P0_14
    [MurataMicroMB.brd, MurataMicroMB.sch]
2015-11-10 [ MB ] move R7-9/15/16//20,C2,SW1-3; pinout list, library update
    [MurataMicroMB.brd, MurataMicroMB.sch]
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2015-11-14 [ MB ] library replace to dp_pcb_local; library update CON1/2/4
    [MurataMicroMB.brd, MurataMicroMB.sch]
2015-11-14 [ FS ] library update CON2/4; pin connection shift to avoid SWD pins
    [MurataBLE_FS.brd, MurataBLE_FS.sch]
2015-11-14 [ 58x ] add fiducial; increase sub board width; move whole board by 1mm North-East; add some value to parts
    [DA14580_QFN40_0v5.brd, DA14580_QFN40_0v5.sch]
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2015-12-01 [ 58x ] IC1 - tCream; add a selecter (580 or 583)
    [DA14580_QFN40_0v5.brd, DA14580_QFN40_0v5.sch]
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2015-12-02 [ SD ] library update; add SWD connector; add Flash;
    [MurataSD.brd, MurataSD.sch]
2015-12-03 [ SD ] disconnect VPP; SPI uses P0_4 to P0_7
    [MurataSD.brd, MurataSD.sch]
2015-12-03 [ MB ] TP1,2,6,7 changed to use test pin; related Rs movee
    [MurataMicroMB.brd, MurataMicroMB.sch]
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2015-12-06 [ MB ] update package of LED1; add TP_4020; update package of IC2
    [MurataMicroMB.brd, MurataMicroMB.sch]
2015-12-16 [ 58x ] Q1 Digikey number replace
    728-1076-1-ND -> 1253-1342-1-ND
    [DA14580_QFN40_0v5.brd, DA14580_QFN40_0v5.sch]
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2015-12-23 [ 58x ] fork as previous version contains version number, but keep previous one
    [DA14580_QFN40.brd, DA14580_QFN40.sch]
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2016-02-23 IC4 replace package; TR1 and related moves
    [MurataMicroMB.brd, MurataMicroMB.sch]
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2016-03-02 [ USB ] add IC4/5
    replace IC2 symbol; change R11 connection
    [MurataBLE.brd, MurataBLE.sch]
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2016-03-04 [ USB ] library CON1 update; Q1 replace; traces;
    [MurataBLE.brd, MurataBLE.sch]
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2016-03-04 [ USB ] traces
    TODO: SW1-3 library to update to have cream layer
    [MurataBLE.brd]
2016-03-04 [ USB ] fix DRC error
    [MurataBLE.brd]
2016-03-04 [ USB ] fix unnecessary foldings
    [MurataBLE.brd]
2016-03-08 library update; add R12-13(shorted 1005 resistors)
    [MurataBLE.brd, MurataBLE.sch]
2016-03-08 IC3 replace by IC_TTL_7400_SINGLE
    [MurataBLE.brd, MurataBLE.sch]
2016-03-08 [ MB ] IC2 and related fix; library update
    [MurataMicroMB.brd, MurataMicroMB.sch]
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2016-03-08 [ USB ] short register
    [MurataBLE.sch]
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2016-03-10 [ USB ] library update; add X2; move R4/5/11; move LED1
    move revision mark silk
    move name metal
    X1 <> X2 25.4mm distance
    [MurataBLE.brd, MurataBLE.sch]
2016-03-10 [ USB ] get narrower PCB width; CON1 and U1 at center of PCB 31->29mm width dummy header X2
    [MurataBLE.brd, MurataBLE.sch]
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2016-03-16 [ USB ] fix OpenDrain problem
    P0_4 and 5 are used for I2C; has limitation of open drain
    change polarity of LED1 to pull current from 3.3V line
    [MurataBLE.brd, MurataBLE.sch]
2016-03-16 [ USB ] add LED2, R16-18
    UART TX/RX LEDs and blinky a LED combined to LED2
    [MurataBLE.brd, MurataBLE.sch]
2016-03-16 [ USB ] IC1 replace and necessary moves
    [MurataBLE.brd, MurataBLE.sch]
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2016-06-30 [ r0.4 ] update library
    typo fix: P0_32 -> P0_23;
    add 11U35 PinNames for SPI flash
    [MurataBLE.brd, MurataBLE.sch]
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

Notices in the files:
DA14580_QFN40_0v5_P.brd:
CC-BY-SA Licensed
